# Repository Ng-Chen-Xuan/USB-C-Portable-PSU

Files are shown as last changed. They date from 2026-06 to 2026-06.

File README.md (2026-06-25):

# USB-C-Portable-PSU

> Speedrunning USB-C PD powered variable power supply

The USB-C-Portable-PSU Project is a portable variable power supply designed using KiCad v10.

The PCB was designed with a 4 layer stackup of SIG + PWR / GND / GND / PWR + SIG.

<table>
  <tr>
    <td align="center">
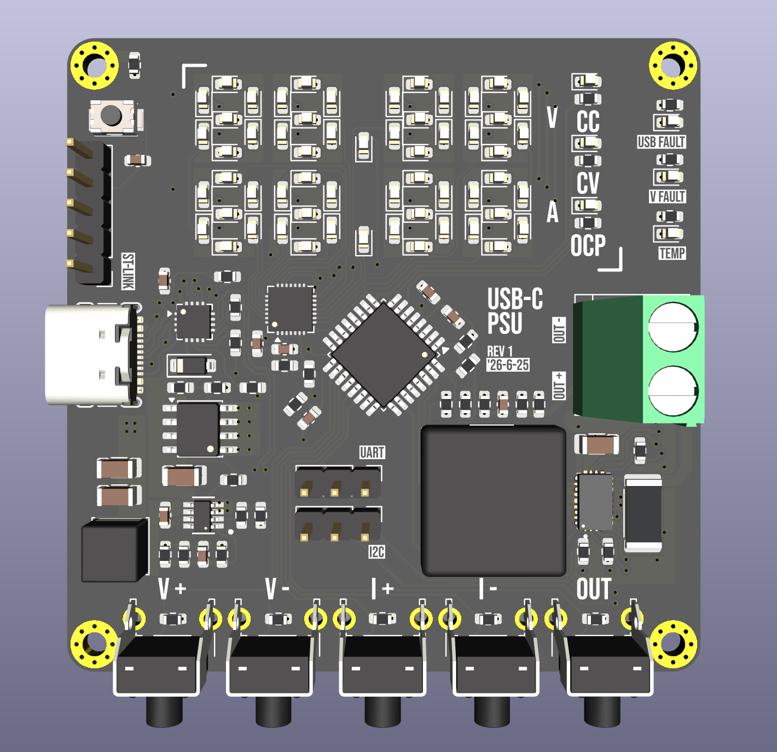
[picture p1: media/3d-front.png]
PCB Front
      <br>
      <b>PCB Front</b>
    </td>
    <td align="center">
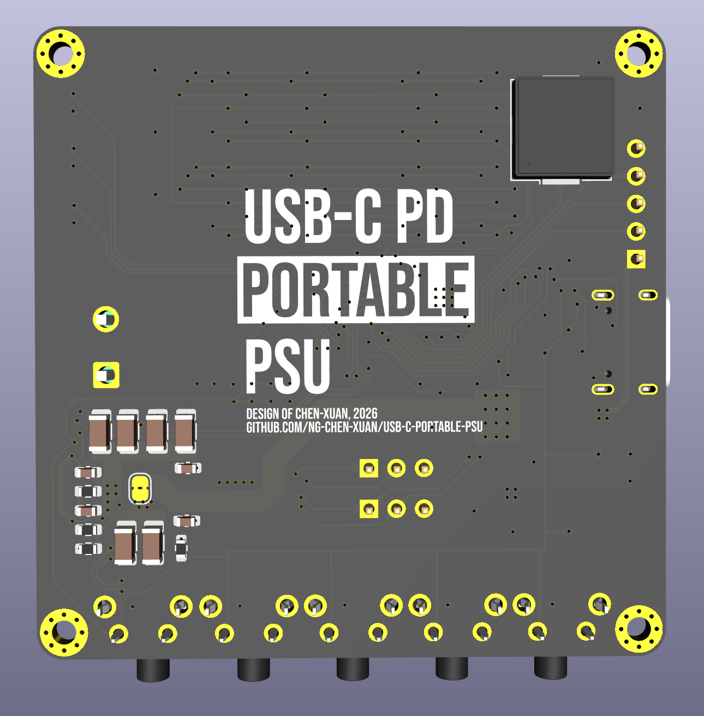
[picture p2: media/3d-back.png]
PCB Back
      <br>
      <b>PCB Back</b>
    </td>
  </tr>
</table>

## Objective

This PCB design serves as both an introduction to power electronics design, as well as a practical tool for hobbyist. Theoretical design practices learnt such as minimising trace inductance, buck-boost converter topology and USB-PD design can be tested in real-life conditions; Practice in programming an LED matrix display and experimentation of the STM32 ecosystem can be gained too.

## Features

* Input:

  * Supports USB-C PD up to 28 V / 3 A
* Output:

  * Variable Voltage Output Selection (3.3 V - 20 V)
  * Variable Constant Current Selection (up to 3 A)
  * Variable OCP Current Selection
* 7 Segment display for live voltage and current
* Safety:

  * Fault detection for USB-C PD
  * Fault detection for buck/boost converter
  * Temperature monitoring using thermistor
* ST-LINK programming header
* Exposed UART and I2C pins

<p align="center">
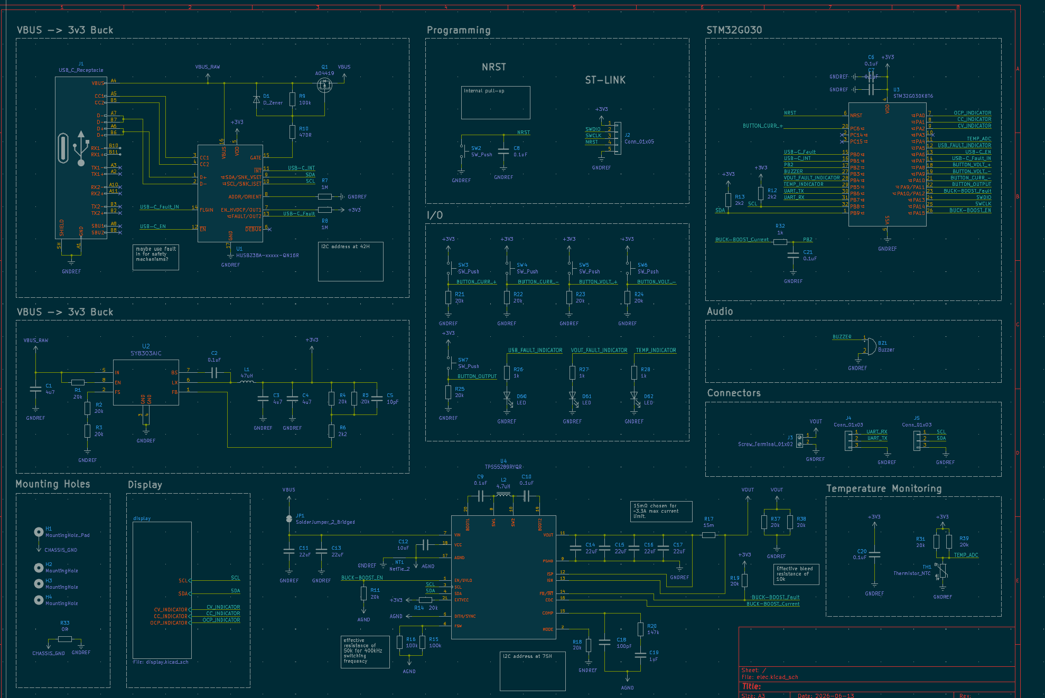
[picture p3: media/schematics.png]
Schematics
  <br>
  <b>Schematics</b>
</p>

<table>
  <tr>
    <td align="center">
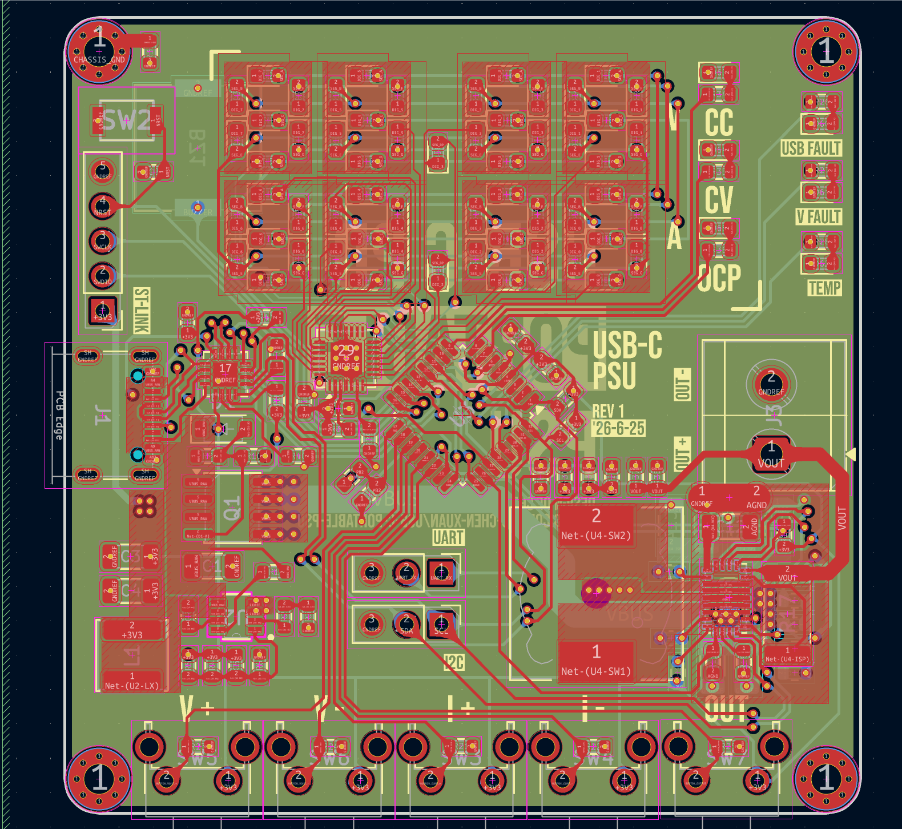
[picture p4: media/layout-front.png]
Layout Front
      <br>
      <b>Layout Front</b>
    </td>
    <td align="center">
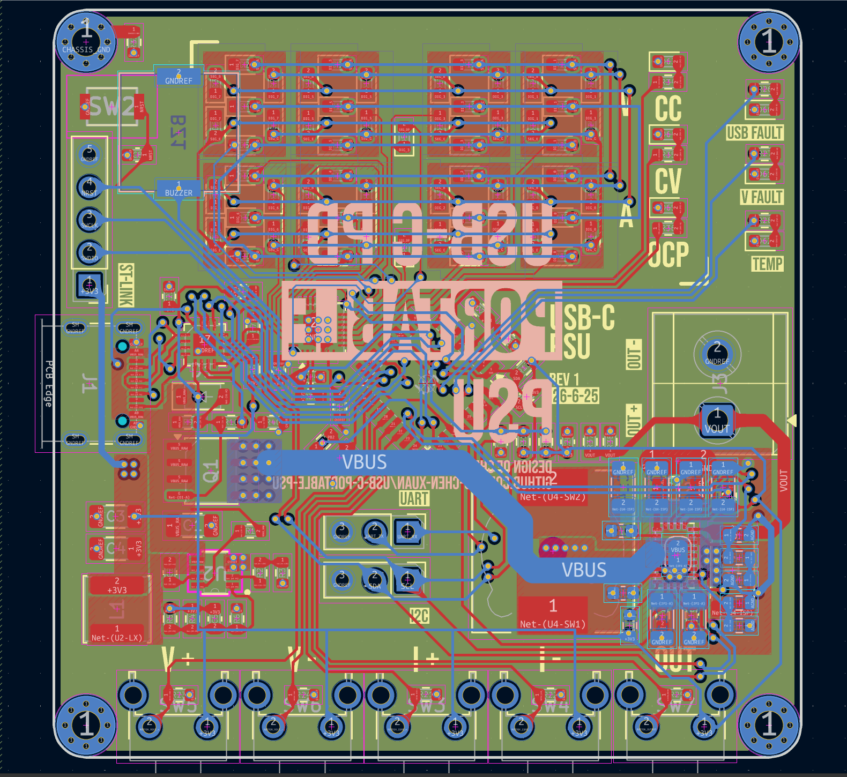
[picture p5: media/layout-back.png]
Layout Back
      <br>
      <b>Layout Back</b>
    </td>
  </tr>
</table>

## File Structure

* [elec/](elec/) - PCB Design Files (KiCad v10)

  * [pcb.pdf](elec/pcb.pdf) - PCB layout reference file
  * [schematics.pdf](elec/schematics.pdf) - PCB schematics reference file
  * [jlcpcb/production_files/](elec/jlcpcb/production_files) - Production files for JLCPCB. Includes BOM, CPL, Gerber files
* [media/](media/) - Images used in this README.md file
* [prod/](prod) - Miscellaneous production files
* [STM32G030K8T6/](STM32G030K8T6/) - STM32CubeMX Configuration file, STM32 Code
* [LICENSE](LICENSE), [LICENSES/](LICENSES/) - License files applicable to this project

## Manufacturing Notes

The design is intended to be manufactured using JLCPCB, with F.Cu assembled by JLCPCB and B.Cu hand-soldered to save on cost.

As of 2026-06-23, it is designed to be used without an enclosure.

## Bill of Materials

### Cost Summary

| Item | Supplier / Method | Cost | Notes |
| --- | --- | ---: | --- |
| JLCPCB order | JLCPCB | USD 144.44 | PCB, top-layer PCBA, extra PCB, and stencil |
| LCSC parts order | LCSC | USD 30.83 | Loose parts order |
| ST-LINK adapter | Taobao | CNY 52.32 | ST-LINK adapter |
| <strong>Total excluding Taobao</strong> | | <strong>USD 175.27</strong> | JLCPCB + LCSC only |
| <strong>Total excluding shipping</strong> | | <strong>USD 175.27 + CNY 52.32</strong> | Listed procurement cost excluding shipping  |

<strong>Total excluding shipping:</strong> USD 175.27 + CNY 52.32 <strong>Approximate USD equivalent:</strong> USD 182.99
Calculation: USD 144.44 + USD 30.83 + CNY 52.32 ≈ USD 182.99

---

### JLCPCB PCBA BOM

Top-layer PCBA only.
Minimum order quantity is <strong>5 PCBs</strong>, so PCBA quantities are shown both <strong>per PCB</strong> and <strong>for 5 PCBs</strong>.

SMD button <strong>SW2 / C115357</strong> is excluded from JLCPCB PCBA.

| Comment | Designator | Footprint | LCSC Part # | Qty / PCB | Total Qty for 5 PCBs |
| --- | --- | --- | --- | ---: | ---: |
| 0.1uF | C10, C2, C20, C21, C24, C6, C7, C8, C9 | C_0603_1608Metric | C14663 | 9 | 45 |
| 0R | R33 | R_0603_1608Metric | C21189 | 1 | 5 |
| 100k | R15, R16, R9 | R_0603_1608Metric | C25803 | 3 | 15 |
| 100pF | C18 | C_0603_1608Metric | C14858 | 1 | 5 |
| 10pF | C5 | C_0603_1608Metric | C1634 | 1 | 5 |
| 10uF | C12 | C_1206_3216Metric | C13585 | 1 | 5 |
| 147k | R20 | R_0603_1608Metric | C22878 | 1 | 5 |
| 15m | R17 | R_2512_6332Metric | C459682 | 1 | 5 |
| 1M | R40, R7, R8 | R_0603_1608Metric | C22935 | 3 | 15 |
| 1k | R26, R27, R28, R32, R34, R35, R36 | R_0603_1608Metric | C21190 | 7 | 35 |
| 1uF | C19, C22, C23 | C_0603_1608Metric | C15849 | 3 | 15 |
| 20k | R1, R11, R14, R18, R19, R2, R21, R22, R23, R24, R25, R29, R3, R30, R31, R37, R38, R39, R4, R41, R5 | R_0603_1608Metric | C4184 | 21 | 105 |
| 2k2 | R12, R13, R6 | R_0603_1608Metric | C4190 | 3 | 15 |
| 4.7uH | L2 | L_12x12mm_H8mm | C24548 | 1 | 5 |
| 470R | R10 | R_0603_1608Metric | C23179 | 1 | 5 |
| 47uH | L1 | L_APV_ANR5040 | C9392 | 1 | 5 |
| 4u7 | C1, C3, C4 | C_1206_3216Metric | C29823 | 3 | 15 |
| AO4419 | Q1 | SOIC-8-1EP_3.9x4.9mm_P1.27mm_EP2.29x3mm_ThermalVias | C29205 | 1 | 5 |
| Buzzer | BZ1 | Buzzer_Murata_PKMCS0909E | C391035 | 1 | 5 |
| D_Zener | D1 | D_SOD-123 | C2103 | 1 | 5 |
| HUSB238A-xxxxx-QN16R | U1 | WQFN-16-1EP_3x3mm_P0.5mm_EP1.75x1.75mm | C24833806 | 1 | 5 |
| IS31FL3731-QF | U6 | QFN-28-1EP_4x4mm_P0.4mm_EP2.3x2.3mm | C191206 | 1 | 5 |
| LED | D10, D11, D12, D13, D14, D15, D16, D17, D18, D19, D2, D20, D21, D22, D23, D24, D25, D26, D27, D28, D29, D3, D30, D31, D32, D33, D34, D35, D36, D37, D38, D39, D4, D40, D41, D42, D43, D44, D45, D46, D47, D48, D49, D5, D50, D51, D52, D53, D54, D55, D56, D57, D58, D59, D6, D60, D61, D62, D63, D64, D65, D7, D8, D9 | LED_0603_1608Metric | C2286 | 64 | 320 |
| STM32G030K8T6 | U3 | LQFP-32_7x7mm_P0.8mm | C431631 | 1 | 5 |
| SW_Push | SW3, SW4, SW5, SW6, SW7 | SW_Tactile_SPST_Angled_PTS645Vx58-2LFS | C86476 | 5 | 25 |
| SY8303AIC | U2 | TSOT_303AIC_SGY | C97054 | 1 | 5 |
| TPS55289RYQR | U4 | VREG_TPS55289RYQR | C5942077 | 1 | 5 |
| Thermistor_NTC | TH1 | R_0603_1608Metric | C13564 | 1 | 5 |
| USB_C_Receptacle | J1 | USB_C_Receptacle_GCT_USB4105-xx-A_16P_TopMnt_Horizontal | C5178539 | 1 | 5 |

<strong>JLCPCB PCBA placed quantity:</strong> 140 components per PCB <strong>Total placed components for MOQ 5:</strong> 700 components

---

### Excluded from JLCPCB PCBA

| Comment | Designator | Footprint  | LCSC Part # | Qty / PCB | Total Qty for 5 PCBs | Reason |
| --- | --- | --- | --- | ---: | ---: | --- |
| SW_Push | SW2 | SKRKAEE020 | C115357 | 1 | 5 | Excluded SMD button |

---

### Hand-Soldered / Not Included in JLCPCB PCBA

These parts are not included in JLCPCB PCBA and are intended to be hand-soldered.

| Comment | Designator | Footprint | Qty / PCB | Total Qty for 5 PCBs |
| --- | --- | --- | ---: | ---: |
| Screw_Terminal_01x02 | J3 | TerminalBlock_CUI_TB007-508-02_1x02_P5.08mm_Horizontal | 1 | 5 |
| Conn_01x05 | J2 | PinHeader_1x05_P2.54mm_Vertical | 1 | 5 |
| Conn_01x03 | J4 | PinHeader_1x03_P2.54mm_Vertical | 1 | 5 |
| Conn_01x03 | J5 | PinHeader_1x03_P2.54mm_Vertical | 1 | 5 |
| 22uF | C14 | C_1206_3216Metric | 1 | 5 |
| 22uF | C16 | C_1206_3216Metric | 1 | 5 |
| 22uF | C13 | C_1206_3216Metric | 1 | 5 |
| 22uF | C11 | C_1206_3216Metric | 1 | 5 |
| 22uF | C17 | C_1206_3216Metric | 1 | 5 |
| 22uF | C15 | C_1206_3216Metric | 1 | 5 |

---

### LCSC Separate Purchase / Spare Parts

These parts are purchased separately from LCSC as loose parts, including spare parts, rework parts, hand-soldered parts, and parts excluded from JLCPCB PCBA.

| LCSC Part # | MPN | Manufacturer | Package | Description | Qty | Unit Price (USD) | Extended Price (USD) |
| --- | --- | --- | --- | --- | --: | ---: | ---: |
| C342620 | C3216X5R1V226MTJ00E | TDK | 1206 | 22uF ±20% 35V Ceramic Capacitor X5R 1206 |  30 | 0.3812 | 11.44 |
| C22878 | 0603WAF1473T5E | UNI-ROYAL | 0603 | 147kΩ ±1% 100mW 0603 Thick Film Resistor | 100 | 0.0022 | 0.22 |
| C14858 | CL10C101JB8NNNC | Samsung Electro-Mechanics | 0603 | 100pF ±5% 50V Ceramic Capacitor C0G 0603 | 100 | 0.0085 | 0.85 |
| C5199872 | CL10B105KB8NQNC | Samsung Electro-Mechanics | 0603 | 1uF ±10% 50V Ceramic Capacitor X7R 0603 | 100 | 0.0262 | 2.62 |
| C2906980 | FRC0603F1003TS | FOJAN | 0603 | 100kΩ ±1% 100mW 0603 Thick Film Resistor | 100 | 0.0019 | 0.19 |
| C2907011 | FRC0603F2002TS | FOJAN | 0603 | 20kΩ ±1% 100mW 0603 Thick Film Resistor | 100 | 0.0018 | 0.18 |
| C1591 | CL10B104KB8NNNC | Samsung Electro-Mechanics | 0603 | 100nF ±10% 50V Ceramic Capacitor X7R 0603 | 100 | 0.0142 | 1.42 |
| C391035 | FUET-9018 | FUET | SMD,9x9mm | Buzzers Passive (Externally Driven) Piezoelectric 4kHz 65dB SMD,9x9mm |  10 | 0.4248 | 4.25 |
| C115357 | SKRKAEE020 | ALPSALPINE | SMD,3.9x2.9mm | Tactile Switch SPST 2mm 3.9mm x 2.9mm Surface Mount |  20 | 0.1333 | 2.67 |
| C3816270 | TB007-508-02BE | CUI | Through Hole,P=5.08mm | 2 Position Wire to Board Terminal Block 5.08mm |  10 | 0.6764 | 6.76 |
| C2907075 | FRC0603F9103TS | FOJAN | 0603 | 910kΩ ±1% 100mW 0603 Thick Film Resistor | 100 | 0.0023 | 0.23 |

<strong>LCSC order total:</strong> USD 30.83

---

### Taobao Separate Purchase

| Item | Supplier | Qty | Cost | Notes |
| --- | --- | --: | ---: | --- |
| ST-LINK adapter | Taobao | 1 | CNY 52.32 | Used for programming/debugging adapter setup |

---

### Notes

* JLCPCB PCBA is for top-layer assembly only.
* JLCPCB's PCBA minimum order quantity is 5 PCBs, so PCBA quantities are shown both per PCB and for 5 PCBs.
* The SMD button `SW2 / C115357` is excluded from JLCPCB PCBA and purchased separately from LCSC.
* Hand-soldered parts are not included in JLCPCB PCBA.
* Loose LCSC parts include spare parts, rework parts, hand-soldered parts, and parts excluded from JLCPCB PCBA.
* The ST-LINK adapter is purchased separately from Taobao.

<table>
  <tr>
    <td align="center">
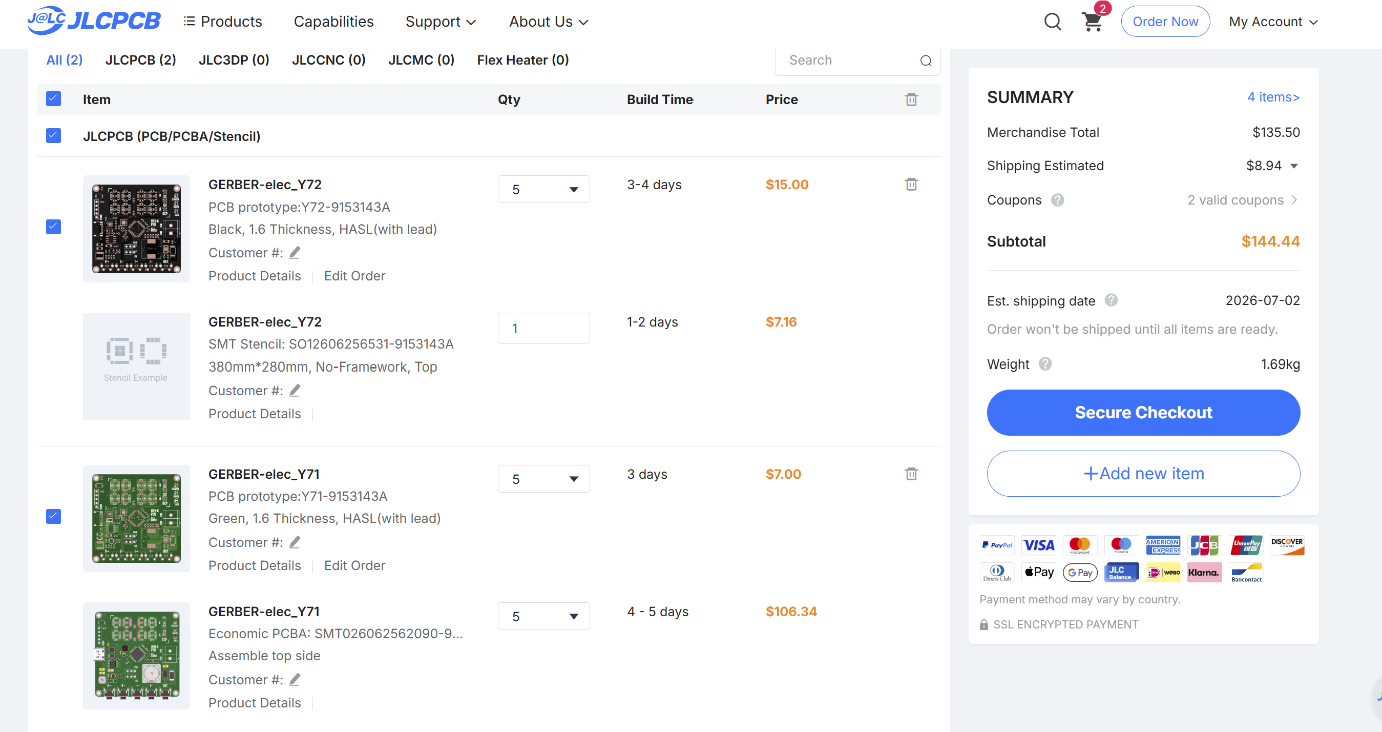
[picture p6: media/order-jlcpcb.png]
JLCPCB Order
      <br>
      <b>JLCPCB Order</b>
    </td>
    <td align="center">
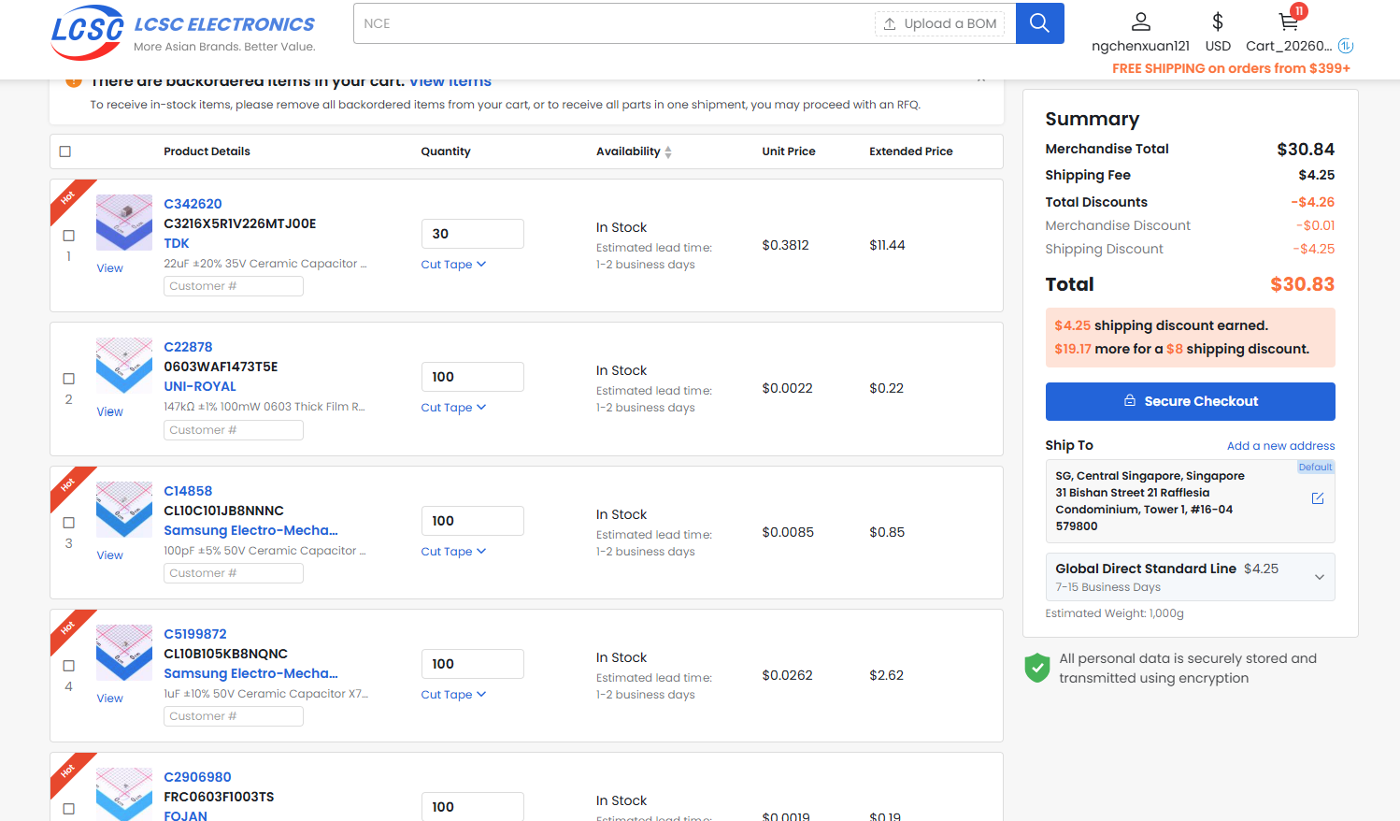
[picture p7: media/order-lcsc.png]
LCSC Order
      <br>
      <b>LCSC Order</b>
    </td>
  </tr>
</table>

## License

This project uses multiple licenses:

* Hardware design files, including schematics, PCB layout files, Gerbers, BOM files, pick-and-place files, mechanical CAD files, and enclosure designs: <strong>CERN-OHL-S-2.0</strong>
* Firmware and software source code: <strong>GPL-3.0-only</strong>
* Documentation, images, diagrams, and build instructions: <strong>CC-BY-SA-4.0</strong>

Full license texts are available in the `LICENSES/` directory.

## Contact

Contact the author at [contact@ngchenxuan.com](mailto:contact@ngchenxuan.com) for any enquiries related to this project.

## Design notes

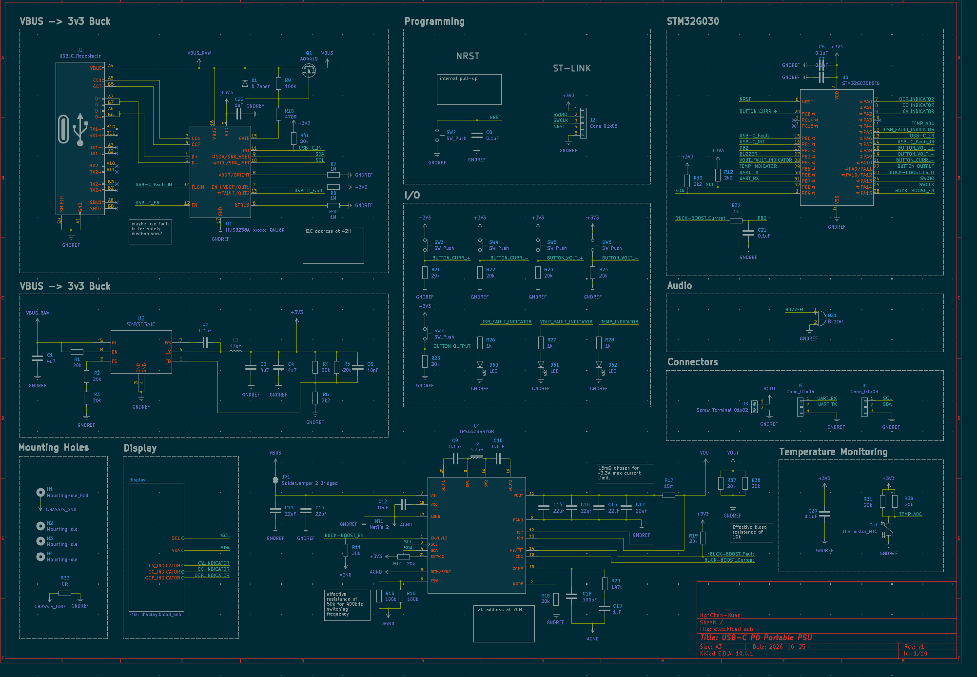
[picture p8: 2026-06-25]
media/schematic.png

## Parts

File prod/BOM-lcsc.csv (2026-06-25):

Index | LCSC# | MPN | Manufacturer | Package | Customer # | Description | RoHS | Quantity | MOQ | Multiple | Unit Price($) | Extended Price($) | Product Link
1 | C342620 | C3216X5R1V226MTJ00E | TDK | 1206 |  | 22uF ±20% 35V Ceramic Capacitor X5R 1206 | yes | 30 | 10 | 10 | 0.3812 | 11.44 | https://www.lcsc.com/product-detail/C342620.html
2 | C22878 | 0603WAF1473T5E | UNI-ROYAL | 0603 |  | 147kΩ ±1% 100mW 0603 Thick Film Resistor | yes | 100 | 100 | 100 | 0.0022 | 0.22 | https://www.lcsc.com/product-detail/C22878.html
3 | C14858 | CL10C101JB8NNNC | Samsung Electro-Mechanics | 0603 |  | 100pF ±5% 50V Ceramic Capacitor C0G 0603 | yes | 100 | 100 | 100 | 0.0085 | 0.85 | https://www.lcsc.com/product-detail/C14858.html
4 | C5199872 | CL10B105KB8NQNC | Samsung Electro-Mechanics | 0603 |  | 1uF ±10% 50V Ceramic Capacitor X7R 0603 | yes | 100 | 50 | 50 | 0.0262 | 2.62 | https://www.lcsc.com/product-detail/C5199872.html
5 | C2906980 | FRC0603F1003TS | FOJAN | 0603 |  | 100kΩ ±1% 100mW 0603 Thick Film Resistor | yes | 100 | 100 | 100 | 0.0019 | 0.19 | https://www.lcsc.com/product-detail/C2906980.html
6 | C2907011 | FRC0603F2002TS | FOJAN | 0603 |  | 20kΩ ±1% 100mW 0603 Thick Film Resistor | yes | 100 | 100 | 100 | 0.0018 | 0.18 | https://www.lcsc.com/product-detail/C2907011.html
7 | C1591 | CL10B104KB8NNNC | Samsung Electro-Mechanics | 0603 |  | 100nF ±10% 50V Ceramic Capacitor X7R 0603 | yes | 100 | 100 | 100 | 0.0142 | 1.42 | https://www.lcsc.com/product-detail/C1591.html
8 | C391035 | FUET-9018 | FUET | SMD,9x9mm |  | Buzzers Passive (Externally Driven) Piezoelectric 4kHz 65dB SMD,9x9mm | yes | 10 | 1 | 1 | 0.4248 | 4.25 | https://www.lcsc.com/product-detail/C391035.html
9 | C115357 | SKRKAEE020 | ALPSALPINE | SMD,3.9x2.9mm |  | Tactile Switch SPST 2mm 3.9mm x 2.9mm Surface Mount | yes | 20 | 5 | 5 | 0.1333 | 2.67 | https://www.lcsc.com/product-detail/C115357.html
10 | C3816270 | TB007-508-02BE | CUI | Through Hole,P=5.08mm |  | 2 Position Wire to Board Terminal Block 5.08mm | yes | 10 | 1 | 1 | 0.6764 | 6.76 | https://www.lcsc.com/product-detail/C3816270.html
11 | C2907075 | FRC0603F9103TS | FOJAN | 0603 |  | 910kΩ ±1% 100mW 0603 Thick Film Resistor | yes | 100 | 100 | 100 | 0.0023 | 0.23 | https://www.lcsc.com/product-detail/C2907075.html

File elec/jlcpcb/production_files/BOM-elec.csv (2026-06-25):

Comment | Designator | Footprint | LCSC | Quantity
0.1uF | C10,C2,C20,C21,C24,C6,C7,C8,C9 | C_0603_1608Metric | C14663 | 9
0R | R33 | R_0603_1608Metric | C21189 | 1
100k | R15,R16,R9 | R_0603_1608Metric | C25803 | 3
100pF | C18 | C_0603_1608Metric | C14858 | 1
10pF | C5 | C_0603_1608Metric | C1634 | 1
10uF | C12 | C_1206_3216Metric | C13585 | 1
147k | R20 | R_0603_1608Metric | C22878 | 1
15m | R17 | R_2512_6332Metric | C459682 | 1
1M | R40,R7,R8 | R_0603_1608Metric | C22935 | 3
1k | R26,R27,R28,R32,R34,R35,R36 | R_0603_1608Metric | C21190 | 7
1uF | C19,C22,C23 | C_0603_1608Metric | C15849 | 3
20k | R1,R11,R14,R18,R19,R2,R21,R22,R23,R24,R25,R29,R3,R30,R31,R37,R38,R39,R4,R41,R5 | R_0603_1608Metric | C4184 | 21
2k2 | R12,R13,R6 | R_0603_1608Metric | C4190 | 3
4.7uH | L2 | L_12x12mm_H8mm | C24548 | 1
470R | R10 | R_0603_1608Metric | C23179 | 1
47uH | L1 | L_APV_ANR5040 | C9392 | 1
4u7 | C1,C3,C4 | C_1206_3216Metric | C29823 | 3
AO4419 | Q1 | SOIC-8-1EP_3.9x4.9mm_P1.27mm_EP2.29x3mm_ThermalVias | C29205 | 1
Buzzer | BZ1 | Buzzer_Murata_PKMCS0909E | C391035 | 1
D_Zener | D1 | D_SOD-123 | C2103 | 1
HUSB238A-xxxxx-QN16R | U1 | WQFN-16-1EP_3x3mm_P0.5mm_EP1.75x1.75mm | C24833806 | 1
IS31FL3731-QF | U6 | QFN-28-1EP_4x4mm_P0.4mm_EP2.3x2.3mm | C191206 | 1
LED | D10,D11,D12,D13,D14,D15,D16,D17,D18,D19,D2,D20,D21,D22,D23,D24,D25,D26,D27,D28,D29,D3,D30,D31,D32,D33,D34,D35,D36,D37,D38,D39,D4,D40,D41,D42,D43,D44,D45,D46,D47,D48,D49,D5,D50,D51,D52,D53,D54,D55,D56,D57,D58,D59,D6,D60,D61,D62,D63,D64,D65,D7,D8,D9 | LED_0603_1608Metric | C2286 | 64
STM32G030K8T6 | U3 | LQFP-32_7x7mm_P0.8mm | C431631 | 1
SW_Push | SW2 | SKRKAEE020 | C115357 | 1
SW_Push | SW3,SW4,SW5,SW6,SW7 | SW_Tactile_SPST_Angled_PTS645Vx58-2LFS | C86476 | 5
SY8303AIC | U2 | TSOT_303AIC_SGY | C97054 | 1
TPS55289RYQR | U4 | VREG_TPS55289RYQR | C5942077 | 1
Thermistor_NTC | TH1 | R_0603_1608Metric | C13564 | 1
USB_C_Receptacle | J1 | USB_C_Receptacle_GCT_USB4105-xx-A_16P_TopMnt_Horizontal | C5178539 | 1
Screw_Terminal_01x02 | J3 | TerminalBlock_CUI_TB007-508-02_1x02_P5.08mm_Horizontal |  | 1
Conn_01x05 | J2 | PinHeader_1x05_P2.54mm_Vertical |  | 1
Conn_01x03 | J4 | PinHeader_1x03_P2.54mm_Vertical |  | 1
Conn_01x03 | J5 | PinHeader_1x03_P2.54mm_Vertical |  | 1
22uF | C14 | C_1206_3216Metric |  | 1
22uF | C16 | C_1206_3216Metric |  | 1
22uF | C13 | C_1206_3216Metric |  | 1
22uF | C11 | C_1206_3216Metric |  | 1
22uF | C17 | C_1206_3216Metric |  | 1
22uF | C15 | C_1206_3216Metric |  | 1

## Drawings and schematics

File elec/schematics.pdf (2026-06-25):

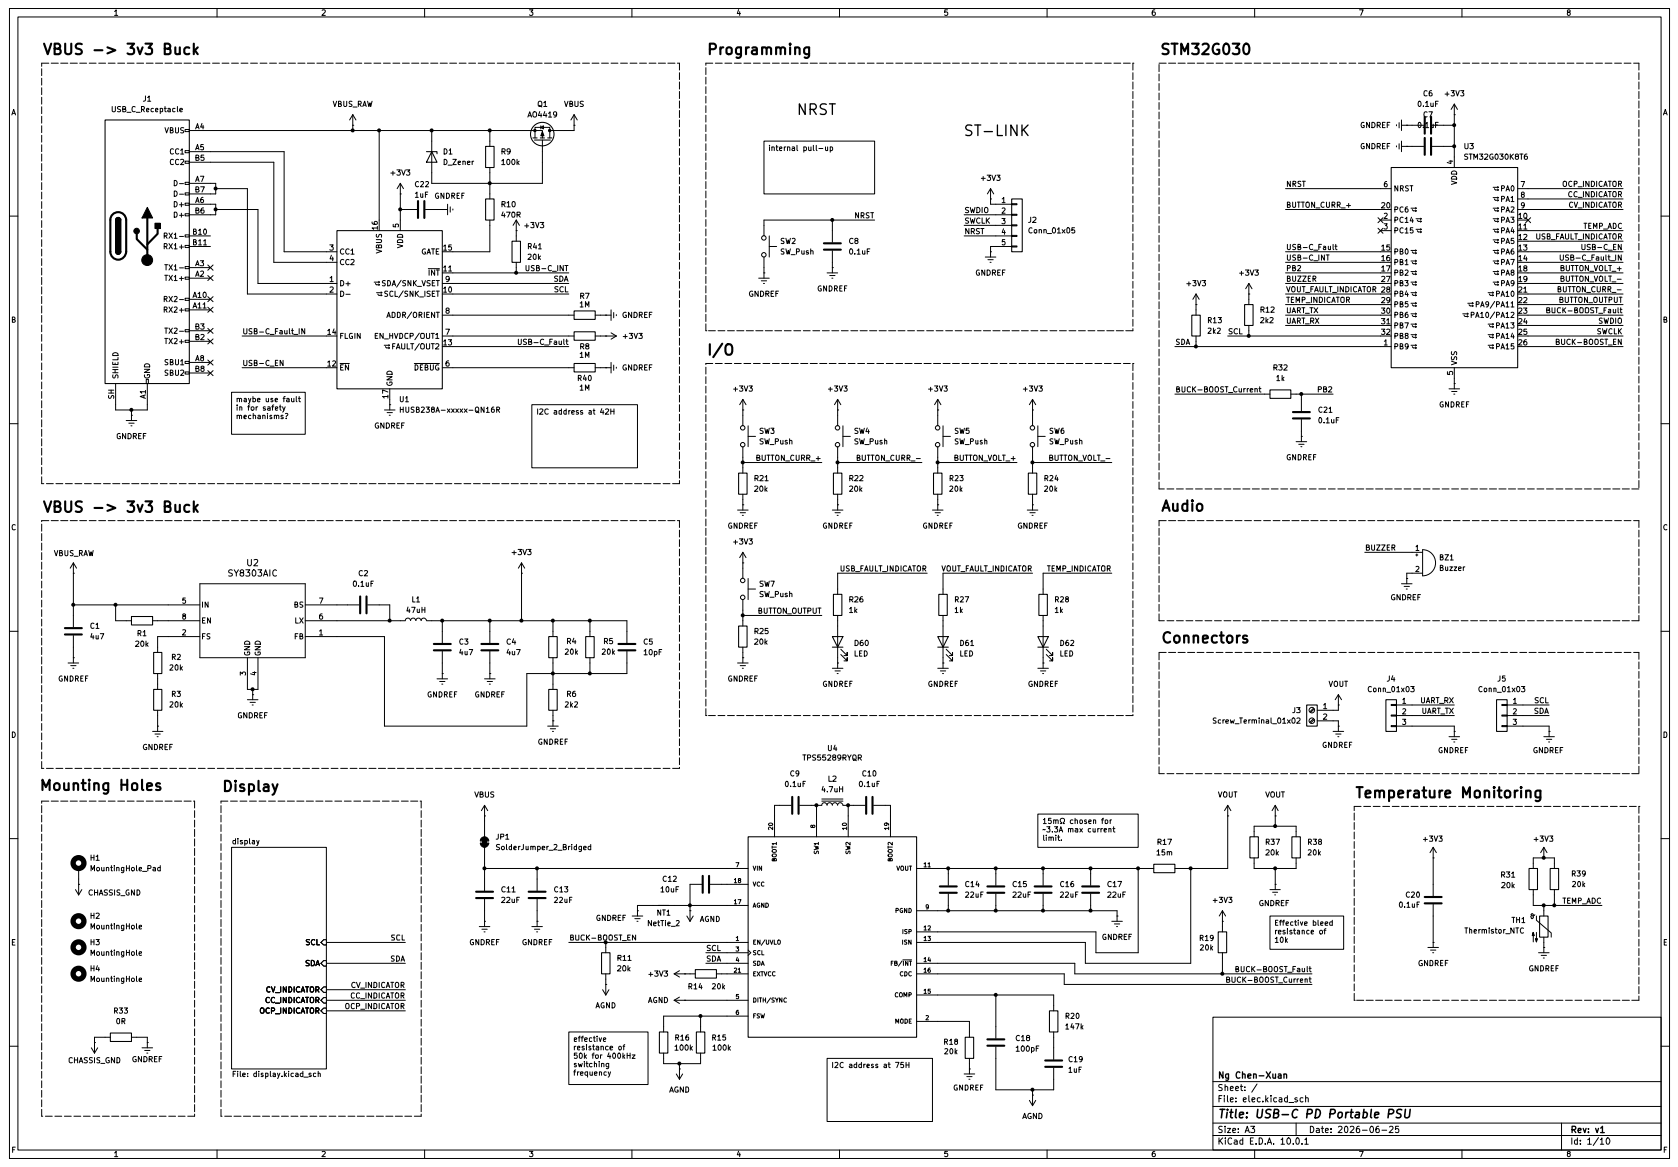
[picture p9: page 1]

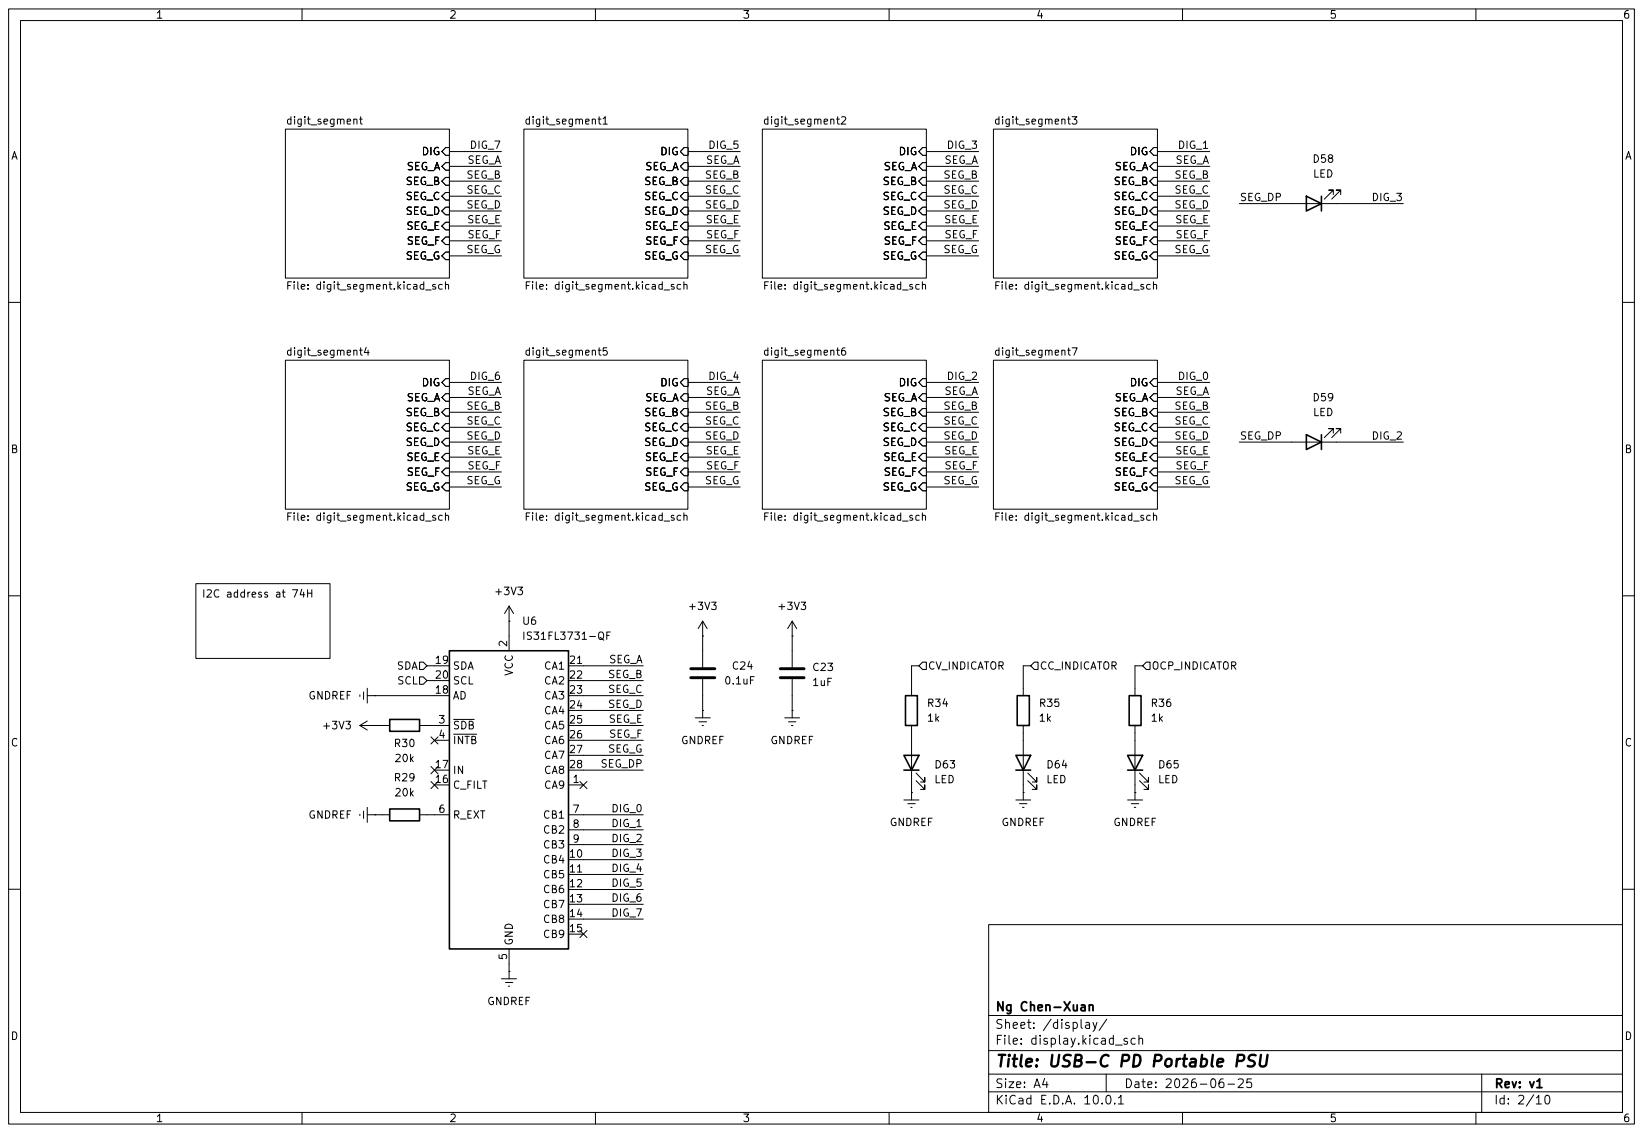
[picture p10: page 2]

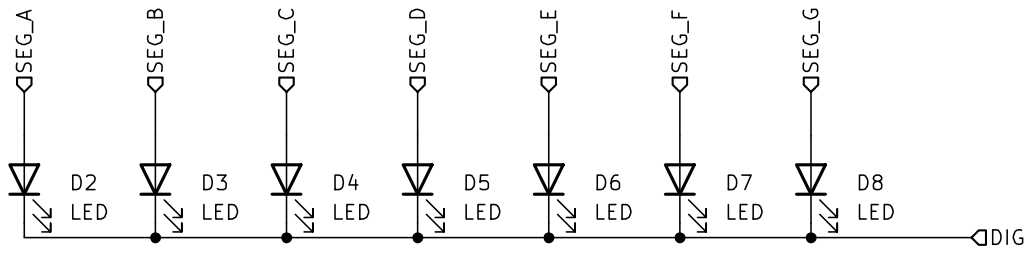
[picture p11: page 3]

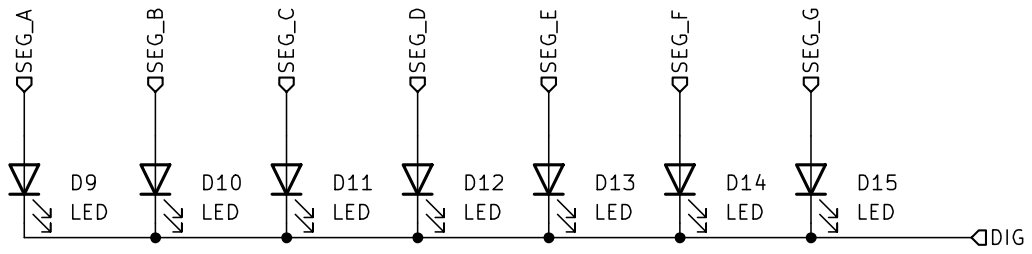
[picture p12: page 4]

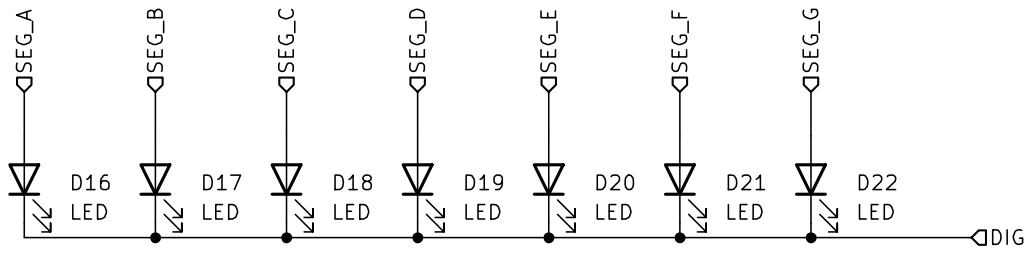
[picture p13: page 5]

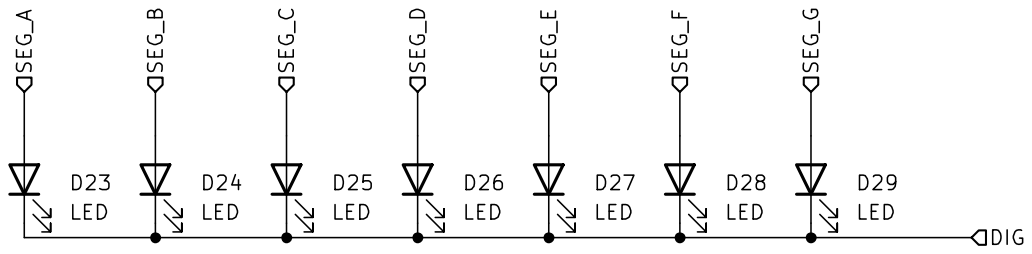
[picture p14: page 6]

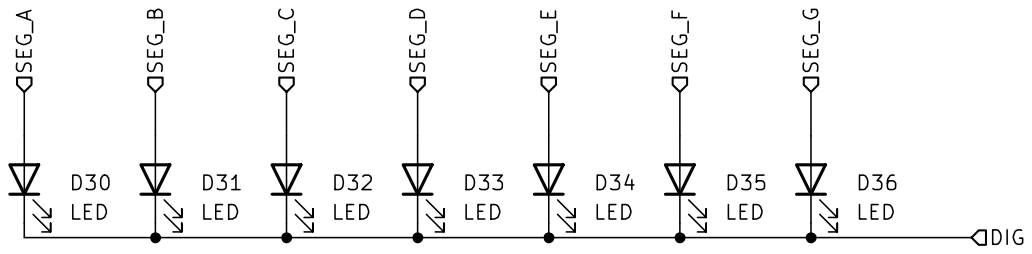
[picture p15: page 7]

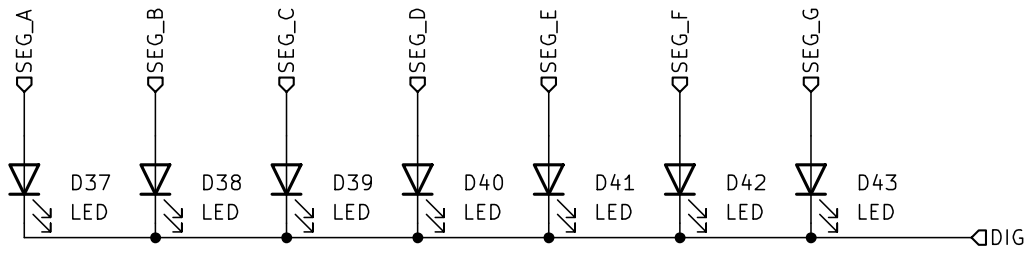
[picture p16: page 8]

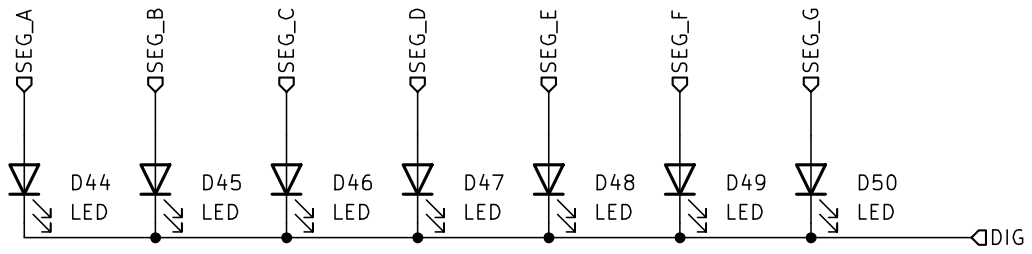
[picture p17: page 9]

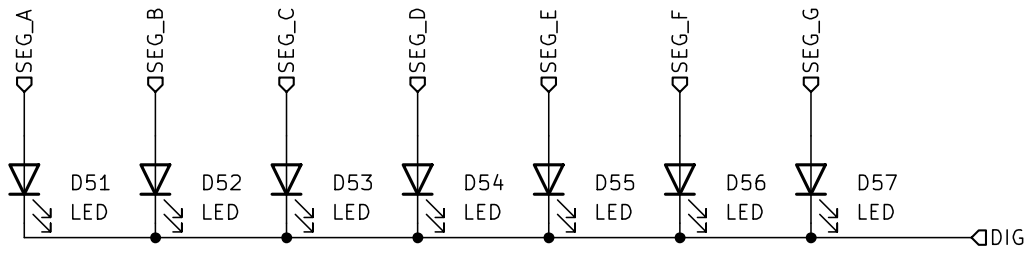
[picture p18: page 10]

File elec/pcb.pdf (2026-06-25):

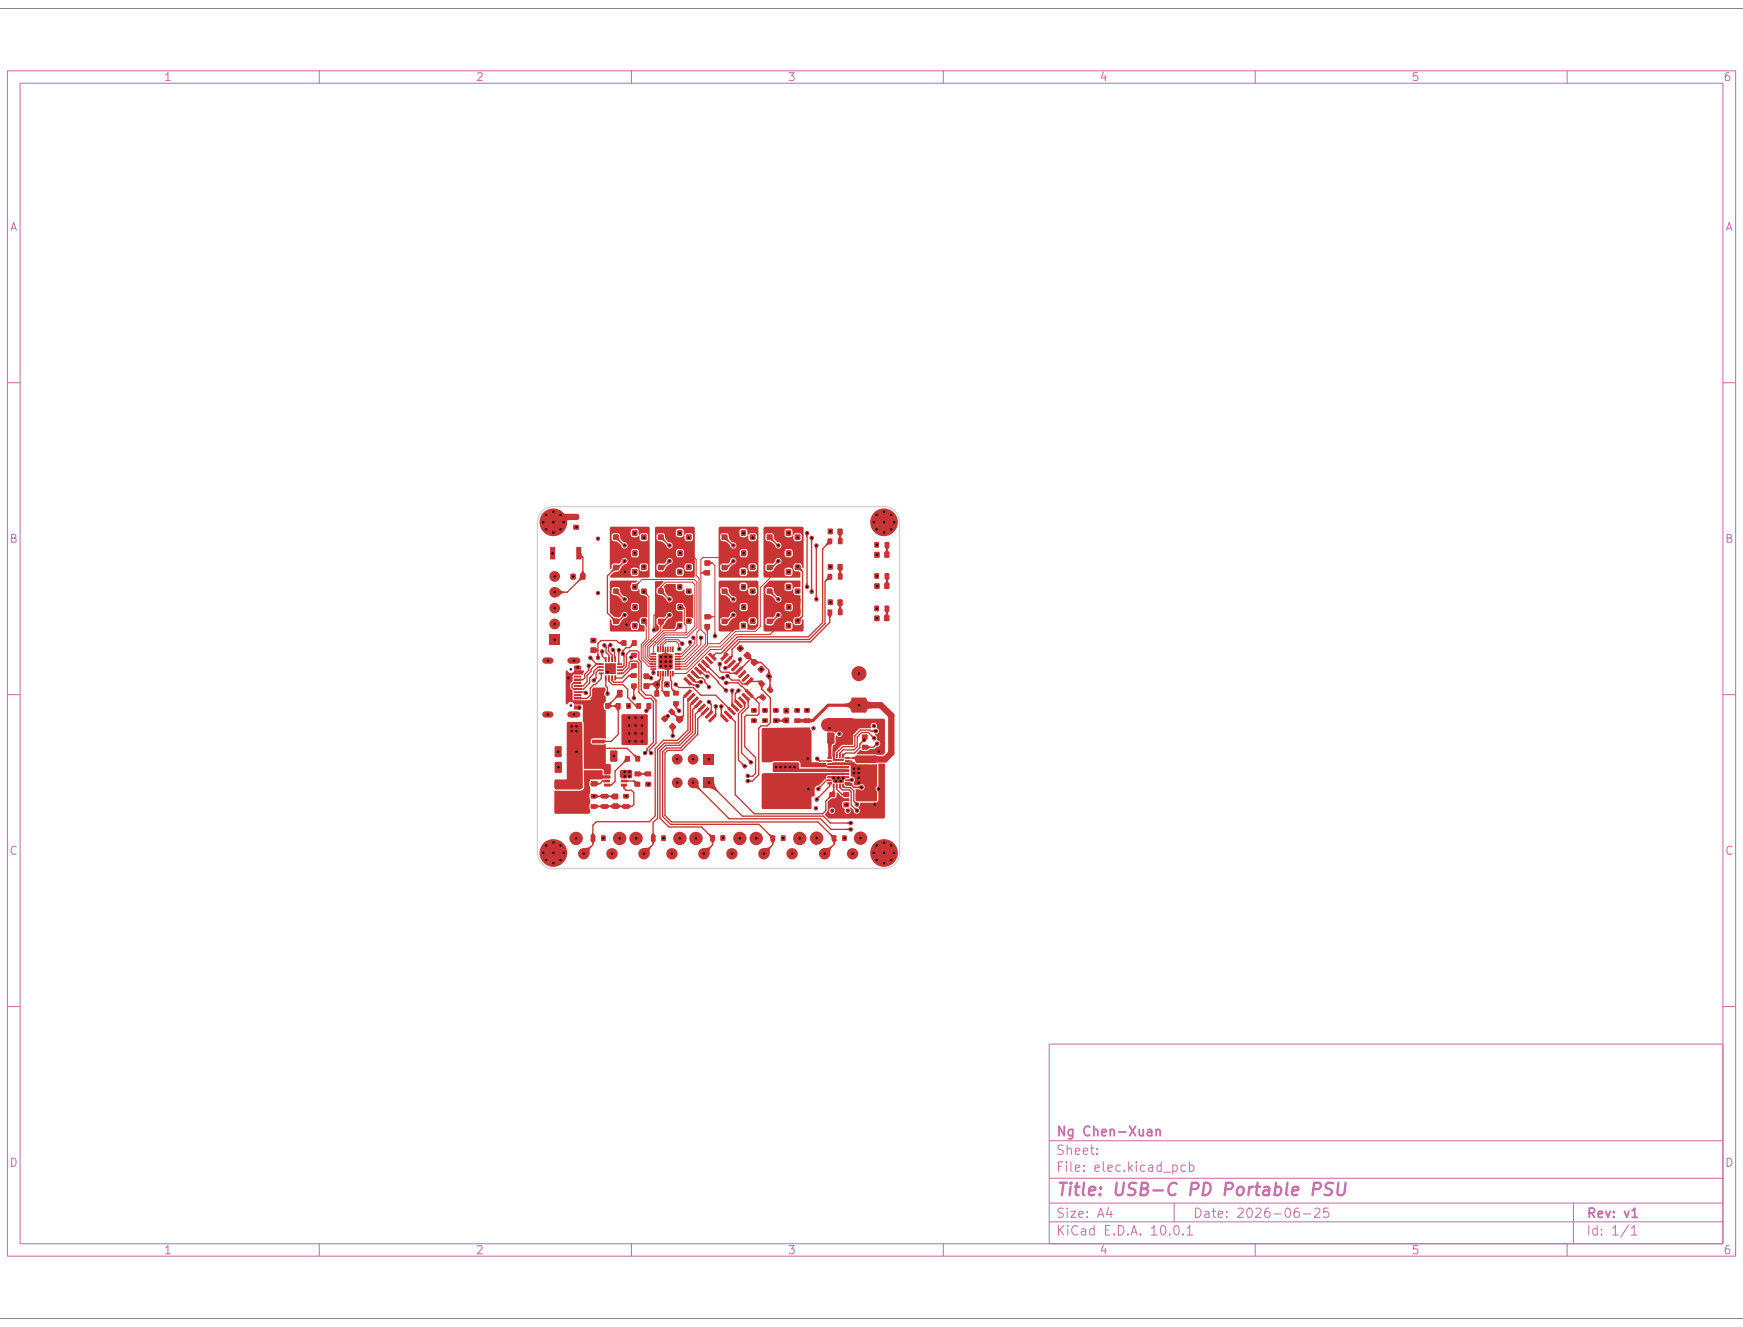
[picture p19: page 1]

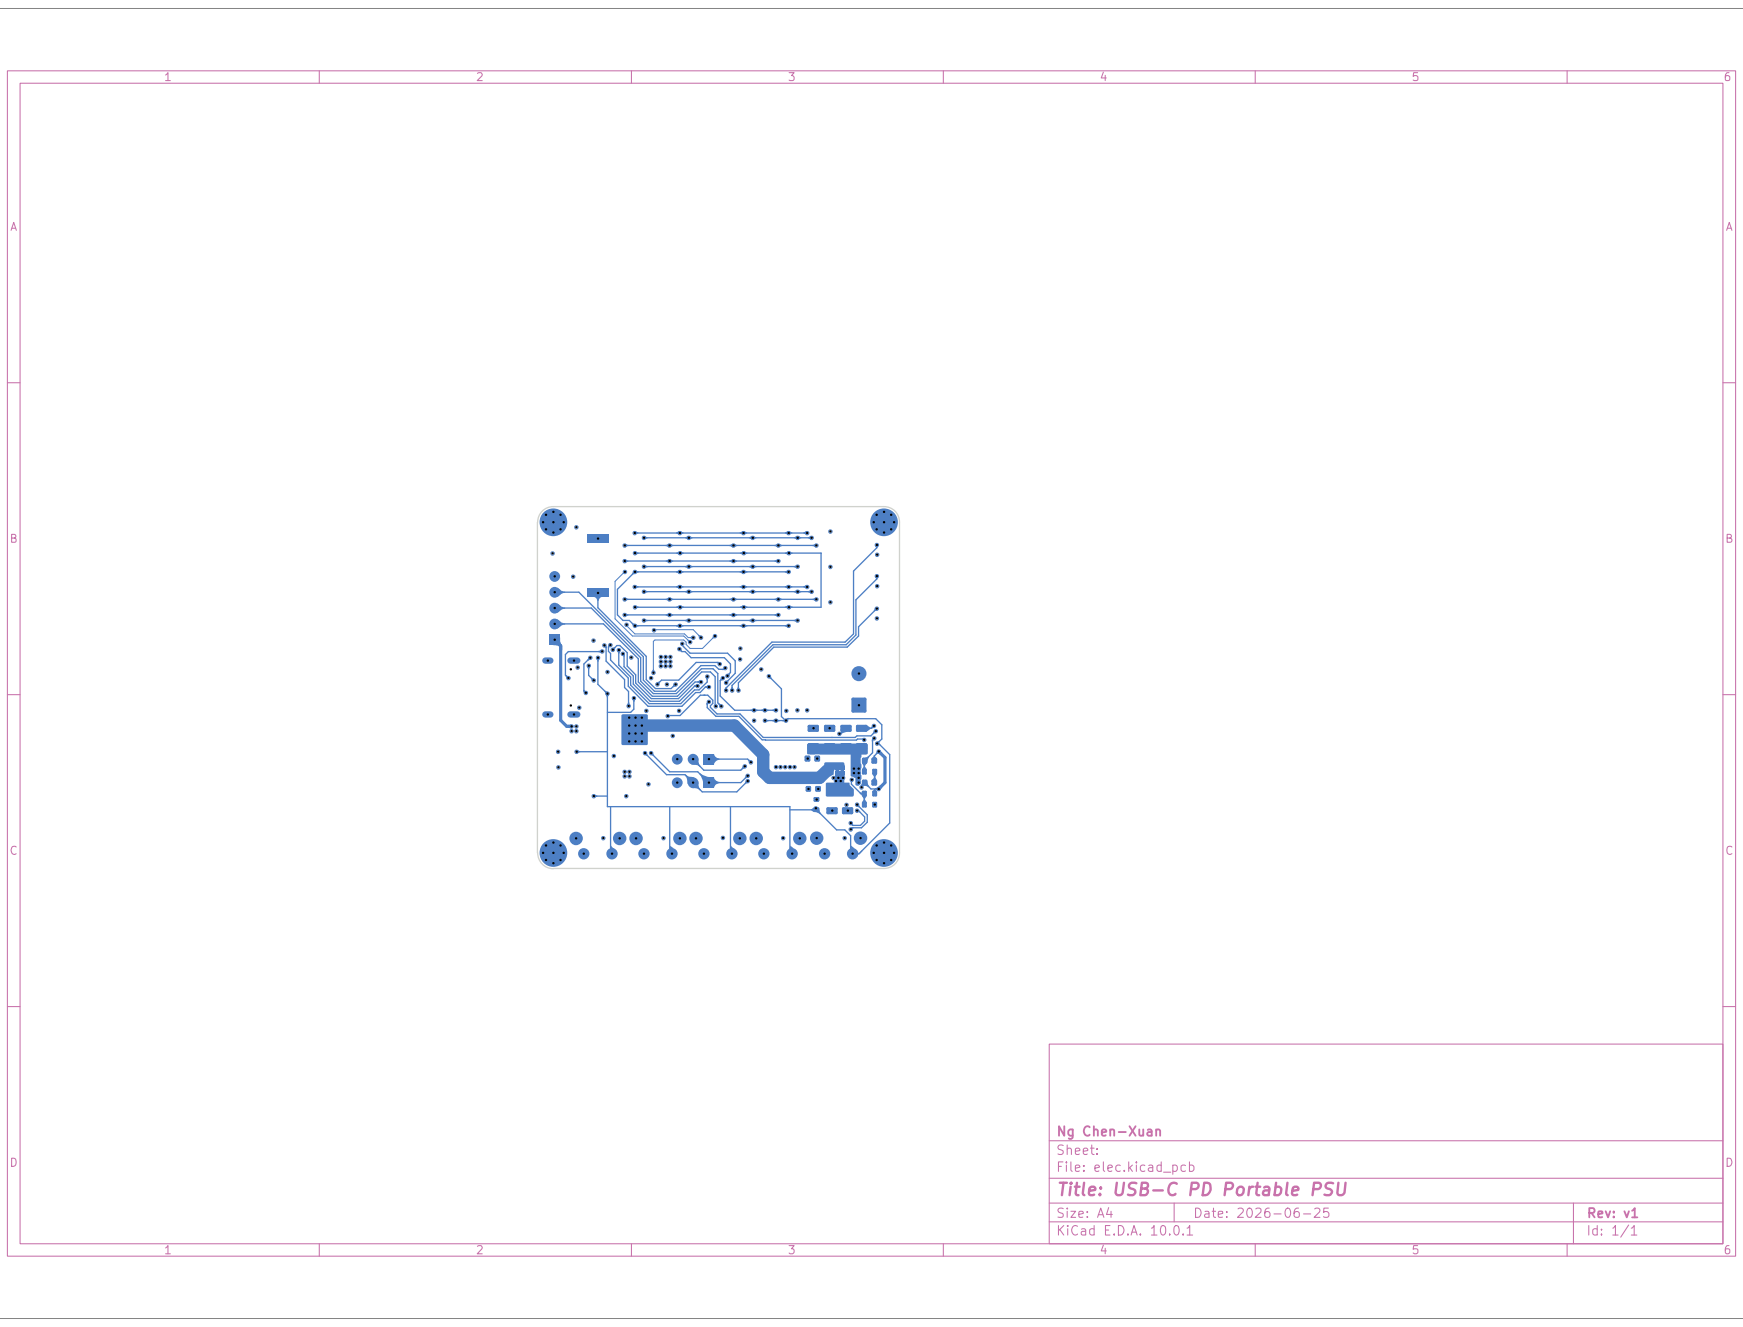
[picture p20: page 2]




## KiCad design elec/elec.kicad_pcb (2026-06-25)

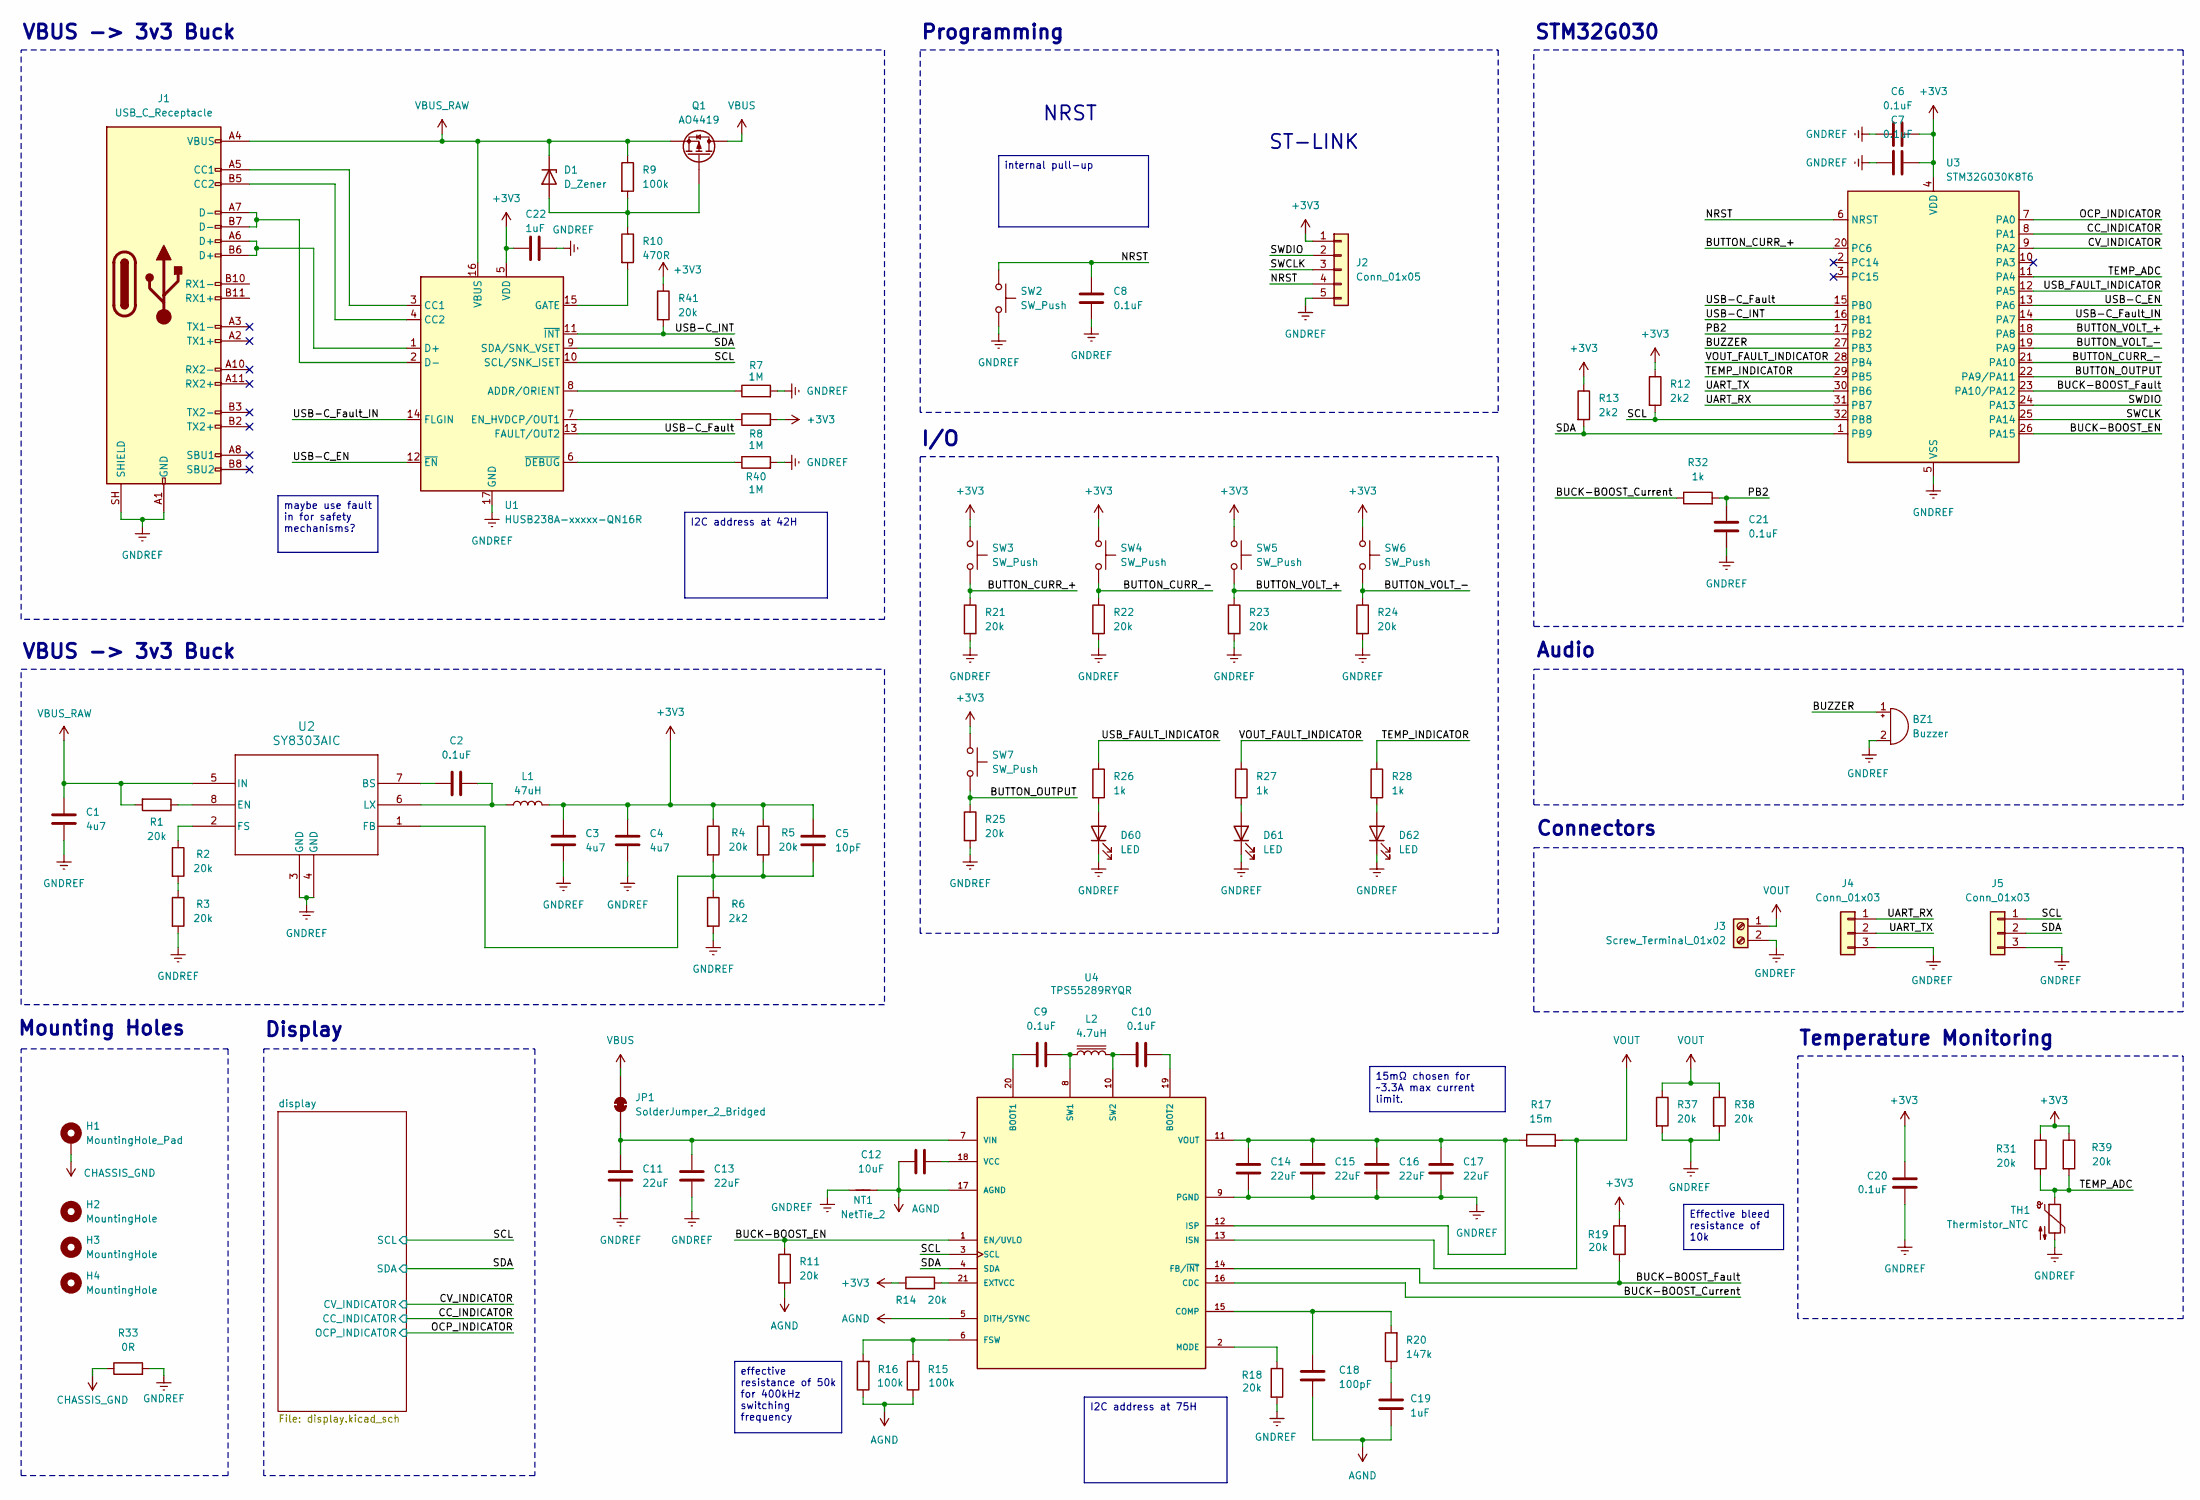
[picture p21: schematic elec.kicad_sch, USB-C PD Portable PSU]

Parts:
BZ1: Buzzer; Buzzer_Murata_PKMCS0909E; LCSC C391035
C1, C3, C4: 4u7; C_1206_3216Metric; LCSC C29823
C2, C6, C7, C8, C9, C10, C20, C21: 0.1uF; C_0603_1608Metric; LCSC C14663
C5: 10pF; C_0603_1608Metric; LCSC C1634
C11, C13, C14, C15, C16, C17: 22uF; C_1206_3216Metric
C12: 10uF; C_1206_3216Metric; LCSC C13585
C18: 100pF; C_0603_1608Metric; LCSC C14858
C19, C22: 1uF; C_0603_1608Metric; LCSC C15849
D1: D_Zener; D_SOD-123; LCSC C2103
D60, D61, D62: LED; LED_0603_1608Metric; LCSC C2286
H1: MountingHole_Pad; MountingHole_2.2mm_M2_Pad_Via
H2, H3, H4: MountingHole; MountingHole_2.2mm_M2_Pad_Via
J1: USB_C_Receptacle; USB_C_Receptacle_GCT_USB4105-xx-A_16P_TopMnt_Horizontal; LCSC C5178539
J2: Conn_01x05; PinHeader_1x05_P2.54mm_Vertical
J3: Screw_Terminal_01x02; TerminalBlock_CUI_TB007-508-02_1x02_P5.08mm_Horizontal
J4, J5: Conn_01x03; PinHeader_1x03_P2.54mm_Vertical
JP1: SolderJumper_2_Bridged; SolderJumper-2_P1.3mm_Bridged2Bar_RoundedPad1.0x1.5mm
L1: 47uH; L_APV_ANR5040; LCSC C9392
L2: 4.7uH; L_12x12mm_H8mm; LCSC C24548
NT1: NetTie_2; NetTie-2_SMD_Pad2.0mm
Q1: AO4419; SOIC-8-1EP_3.9x4.9mm_P1.27mm_EP2.29x3mm_ThermalVias; LCSC C29205
R1, R2, R3, R4, R5, R11, R14, R18, R19, R21, R22, R23, R24, R25, R31, R37, R38, R39: 20k; R_0603_1608Metric; LCSC C4184
R6, R12, R13: 2k2; R_0603_1608Metric; LCSC C4190
R7, R8, R40: 1M; R_0603_1608Metric; LCSC C22935
R9, R15, R16: 100k; R_0603_1608Metric; LCSC C25803
R10: 470R; R_0603_1608Metric; LCSC C23179
R17: 15m; R_2512_6332Metric; LCSC C459682
R20: 147k; R_0603_1608Metric; LCSC C22878
R26, R27, R28, R32: 1k; R_0603_1608Metric; LCSC C21190
R33: 0R; R_0603_1608Metric; LCSC C21189
R41: 20k; R_0603_1608Metric; LCSC C23179
SW2: SW_Push; SKRKAEE020; LCSC C115357
SW3, SW4, SW5, SW6, SW7: SW_Push; SW_Tactile_SPST_Angled_PTS645Vx58-2LFS; LCSC C86476
TH1: Thermistor_NTC; R_0603_1608Metric; LCSC C13564
U1: HUSB238A-xxxxx-QN16R; WQFN-16-1EP_3x3mm_P0.5mm_EP1.75x1.75mm; LCSC C24833806
U2: SY8303AIC; TSOT_303AIC_SGY; LCSC C97054
U3: STM32G030K8T6; LQFP-32_7x7mm_P0.8mm; LCSC C431631
U4: TPS55289RYQR; VREG_TPS55289RYQR; PARTREV August 2022; LCSC C5942077

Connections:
+3V3: C3.1, C4.1, C5.1, C6.2, C7.2, C20.2, C22.1, J2.1, L1.2, R4.1, R5.1, R8.2, R12.1, R13.1, R14.1, R19.2, R31.1, R39.1, R41.1, SW3.1, SW4.1, SW5.1, SW6.1, SW7.1, U1.5 (VDD), U3.4 (VDD); also elsewhere on the board
/BUCK-BOOST_Current: R32.1, U4.16 (CDC)
/BUCK-BOOST_EN: R11.1, U3.26 (PA15), U4.1 (EN/UVLO)
/BUCK-BOOST_Fault: R19.1, U3.23 (PA10/PA12), U4.14 (FB/~INT)
/BUTTON_CURR_+: R21.1, SW3.2, U3.20 (PC6)
/BUTTON_CURR_-: R22.1, SW4.2, U3.21 (PA10)
/BUTTON_OUTPUT: R25.1, SW7.2, U3.22 (PA9/PA11)
/BUTTON_VOLT_+: R23.1, SW5.2, U3.18 (PA8)
/BUTTON_VOLT_-: R24.1, SW6.2, U3.19 (PA9)
/BUZZER: BZ1.1 (+), U3.27 (PB3)
/CC_INDICATOR: U3.8 (PA1); also elsewhere on the board
/CV_INDICATOR: U3.9 (PA2); also elsewhere on the board
/NRST: C8.1, J2.4, SW2.1, U3.6 (NRST)
/OCP_INDICATOR: U3.7 (PA0); also elsewhere on the board
/PB2: C21.2, R32.2, U3.17 (PB2)
/SCL: J5.1, R12.2, U1.10 (SCL/SNK_ISET), U3.32 (PB8), U4.3 (SCL); also elsewhere on the board
/SDA: J5.2, R13.2, U1.9 (SDA/SNK_VSET), U3.1 (PB9), U4.4 (SDA); also elsewhere on the board
/SWCLK: J2.3, U3.25 (PA14)
/SWDIO: J2.2, U3.24 (PA13)
/TEMP_ADC: R31.2, R39.2, TH1.1, U3.11 (PA4)
/TEMP_INDICATOR: R28.1, U3.29 (PB5)
/UART_RX: J4.1, U3.31 (PB7)
/UART_TX: J4.2, U3.30 (PB6)
/USB-C_EN: U1.12 (~EN), U3.13 (PA6)
/USB-C_Fault: U1.13 (FAULT/OUT2), U3.15 (PB0)
/USB-C_Fault_IN: U1.14 (FLGIN), U3.14 (PA7)
/USB-C_INT: R41.2, U1.11 (~INT), U3.16 (PB1)
/USB_FAULT_INDICATOR: R26.1, U3.12 (PA5)
/VOUT_FAULT_INDICATOR: R27.1, U3.28 (PB4)
AGND: C12.2, C18.2, C19.2, NT1.2, R11.2, R15.1, R16.1, U4.5 (DITH/SYNC), U4.17 (AGND)
CHASSIS_GND: H1.1 (1_1), R33.1
GNDREF: BZ1.2 (-), C1.2, C3.2, C4.2, C6.1, C7.1, C8.2, C11.2, C13.2, C14.1, C15.1, C16.1, C17.1, C20.1, C21.1, C22.2, D60.1 (K), D61.1 (K), D62.1 (K), J1.A1 (GND), J1.A12 (GND), J1.B1 (GND), J1.B12 (GND), J1.SH (SHIELD), J2.5, J3.2, J4.3, J5.3, NT1.1, R3.2, R6.2, R7.2, R18.2, R21.2, R22.2, R23.2, R24.2, R25.2, R33.2, R37.2, R38.2, R40.2, SW2.2, TH1.2, U1.17 (GND), U2.3 (GND), U2.4 (GND), U3.5 (VSS), U4.9 (PGND); also elsewhere on the board
unnamed: C19.1, R20.1
unnamed: D1.2 (A), Q1.G, R9.2, R10.1
unnamed: D60.2 (A), R26.2
unnamed: D61.2 (A), R27.2
unnamed: D62.2 (A), R28.2
unnamed: J1.A5 (CC1), U1.3 (CC1)
unnamed: J1.B5 (CC2), U1.4 (CC2)
unnamed: C11.1, C13.1, JP1.1 (A), U4.7 (VIN)
unnamed: R2.2, R3.1
unnamed: R7.1, U1.8 (ADDR/ORIENT)
unnamed: J1.A6 (D+), J1.B6 (D+), U1.1 (D+)
unnamed: J1.A7 (D-), J1.B7 (D-), U1.2 (D-)
unnamed: R8.1, U1.7 (EN_HVDCP/OUT1)
unnamed: R10.2, U1.15 (GATE)
unnamed: R40.1, U1.6 (~DEBUG)
unnamed: C2.1, U2.7 (BS)
unnamed: R1.1, U2.8 (EN)
unnamed: C5.2, R4.2, R5.2, R6.1, U2.1 (FB)
unnamed: R2.1, U2.2 (FS)
unnamed: C2.2, L1.1, U2.6 (LX)
unnamed: C9.2, U4.20 (BOOT1)
unnamed: C10.2, U4.19 (BOOT2)
unnamed: C18.1, R20.2, U4.15 (COMP)
unnamed: R14.2, U4.21 (EXTVCC)
unnamed: R15.2, R16.2, U4.6 (FSW)
unnamed: C14.2, C15.2, C16.2, C17.2, R17.1, U4.11 (VOUT), U4.12 (ISP)
unnamed: R18.1, U4.2 (MODE)
unnamed: C9.1, L2.1, U4.8 (SW1)
unnamed: C10.1, L2.2, U4.10 (SW2)
unnamed: C12.1, U4.18 (VCC)
VBUS: JP1.2 (B), Q1.D
VBUS_RAW: C1.1, D1.1 (K), J1.A4 (VBUS), J1.A9 (VBUS), J1.B4 (VBUS), J1.B9 (VBUS), Q1.S, R1.2, R9.1, U1.16 (VBUS), U2.5 (IN)
VOUT: J3.1, R17.2, R37.1, R38.1, U4.13 (ISN)

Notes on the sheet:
ST-LINK
Mounting Holes
STM32G030
VBUS -> 3v3 Buck
Display
NRST
Connectors
Audio
Temperature Monitoring
I/O
Programming
15mΩ chosen for ~3.3A max current limit.
effective resistance of 50k for 400kHz switching frequency
internal pull-up
Effective bleed resistance of 10k
maybe use fault in for safety mechanisms?
I2C address at 75H
I2C address at 42H

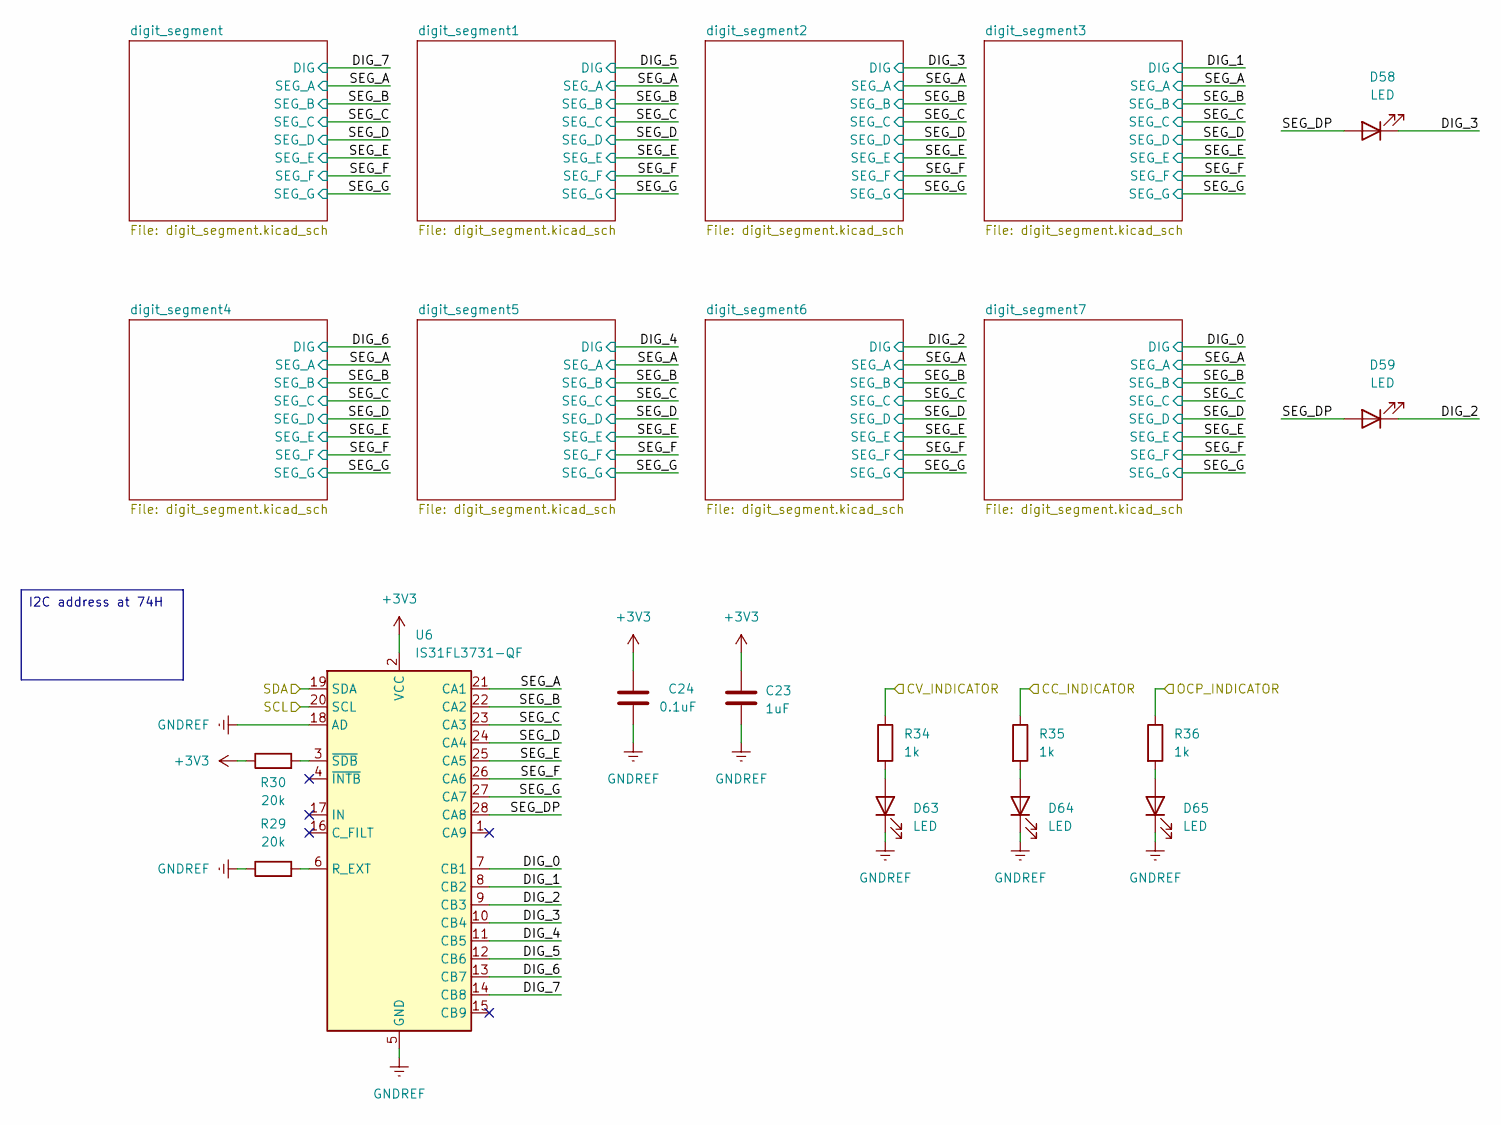
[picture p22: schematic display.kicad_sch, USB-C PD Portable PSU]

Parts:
C23: 1uF; C_0603_1608Metric; LCSC C15849
C24: 0.1uF; C_0603_1608Metric; LCSC C14663
D58, D59, D63, D64, D65: LED; LED_0603_1608Metric; LCSC C2286
R29, R30: 20k; R_0603_1608Metric; LCSC C4184
R34, R35, R36: 1k; R_0603_1608Metric; LCSC C21190
U6: IS31FL3731-QF; QFN-28-1EP_4x4mm_P0.4mm_EP2.3x2.3mm; LCSC C191206

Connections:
+3V3: C23.1, C24.2, R30.1, U6.2 (VCC); also elsewhere on the board
/CC_INDICATOR: R35.1; also elsewhere on the board
/CV_INDICATOR: R34.1; also elsewhere on the board
/OCP_INDICATOR: R36.1; also elsewhere on the board
/SCL: U6.20 (SCL); also elsewhere on the board
/SDA: U6.19 (SDA); also elsewhere on the board
/display/DIG_0: U6.7 (CB1); also elsewhere on the board
/display/DIG_1: U6.8 (CB2); also elsewhere on the board
/display/DIG_2: D59.1 (K), U6.9 (CB3); also elsewhere on the board
/display/DIG_3: D58.1 (K), U6.10 (CB4); also elsewhere on the board
/display/DIG_4: U6.11 (CB5); also elsewhere on the board
/display/DIG_5: U6.12 (CB6); also elsewhere on the board
/display/DIG_6: U6.13 (CB7); also elsewhere on the board
/display/DIG_7: U6.14 (CB8); also elsewhere on the board
/display/SEG_A: U6.21 (CA1); also elsewhere on the board
/display/SEG_B: U6.22 (CA2); also elsewhere on the board
/display/SEG_C: U6.23 (CA3); also elsewhere on the board
/display/SEG_D: U6.24 (CA4); also elsewhere on the board
/display/SEG_DP: D58.2 (A), D59.2 (A), U6.28 (CA8)
/display/SEG_E: U6.25 (CA5); also elsewhere on the board
/display/SEG_F: U6.26 (CA6); also elsewhere on the board
/display/SEG_G: U6.27 (CA7); also elsewhere on the board
GNDREF: C23.2, C24.1, D63.1 (K), D64.1 (K), D65.1 (K), R29.1, U6.5 (GND), U6.18 (AD), U6.29 (GND); also elsewhere on the board
unnamed: D63.2 (A), R34.2
unnamed: D64.2 (A), R35.2
unnamed: D65.2 (A), R36.2
unnamed: R29.2, U6.6 (R_EXT)
unnamed: R30.2, U6.3 (~SDB)

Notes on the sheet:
I2C address at 74H

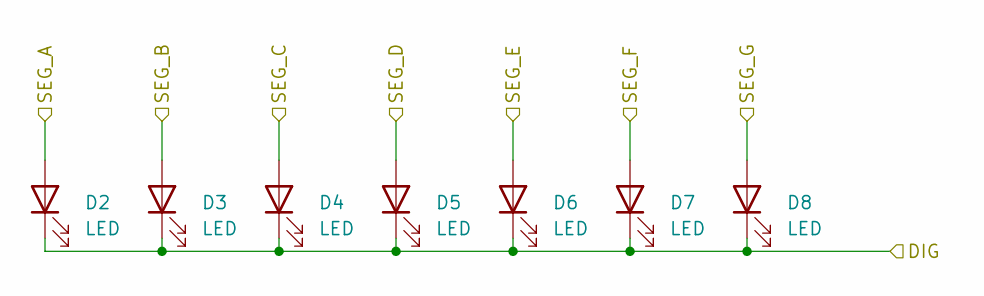
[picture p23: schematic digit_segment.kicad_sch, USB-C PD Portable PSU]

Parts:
D2, D3, D4, D5, D6, D7, D8: LED; LED_0603_1608Metric; LCSC C2286

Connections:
/display/DIG_7: D2.1 (K), D3.1 (K), D4.1 (K), D5.1 (K), D6.1 (K), D7.1 (K), D8.1 (K); also elsewhere on the board
/display/SEG_A: D2.2 (A); also elsewhere on the board
/display/SEG_B: D3.2 (A); also elsewhere on the board
/display/SEG_C: D4.2 (A); also elsewhere on the board
/display/SEG_D: D5.2 (A); also elsewhere on the board
/display/SEG_E: D6.2 (A); also elsewhere on the board
/display/SEG_F: D7.2 (A); also elsewhere on the board
/display/SEG_G: D8.2 (A); also elsewhere on the board

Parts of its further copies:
D9, D10, D11, D12, D13, D14, D15, D16, D17, D18, D19, D20, D21, D22, D23, D24, D25, D26, D27, D28, D29, D30, D31, D32, D33, D34, D35, D36, D37, D38, D39, D40, D41, D42, D43, D44, D45, D46, D47, D48, D49, D50, D51, D52, D53, D54, D55, D56, D57: LED; LED_0603_1608Metric; LCSC C2286

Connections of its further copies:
/display/DIG_0: D51.1 (K), D52.1 (K), D53.1 (K), D54.1 (K), D55.1 (K), D56.1 (K), D57.1 (K); also elsewhere on the board
/display/DIG_1: D23.1 (K), D24.1 (K), D25.1 (K), D26.1 (K), D27.1 (K), D28.1 (K), D29.1 (K); also elsewhere on the board
/display/DIG_2: D44.1 (K), D45.1 (K), D46.1 (K), D47.1 (K), D48.1 (K), D49.1 (K), D50.1 (K); also elsewhere on the board
/display/DIG_3: D16.1 (K), D17.1 (K), D18.1 (K), D19.1 (K), D20.1 (K), D21.1 (K), D22.1 (K); also elsewhere on the board
/display/DIG_4: D37.1 (K), D38.1 (K), D39.1 (K), D40.1 (K), D41.1 (K), D42.1 (K), D43.1 (K); also elsewhere on the board
/display/DIG_5: D9.1 (K), D10.1 (K), D11.1 (K), D12.1 (K), D13.1 (K), D14.1 (K), D15.1 (K); also elsewhere on the board
/display/DIG_6: D30.1 (K), D31.1 (K), D32.1 (K), D33.1 (K), D34.1 (K), D35.1 (K), D36.1 (K); also elsewhere on the board
/display/SEG_A: D9.2 (A), D16.2 (A), D23.2 (A), D30.2 (A), D37.2 (A), D44.2 (A), D51.2 (A); also elsewhere on the board
/display/SEG_B: D10.2 (A), D17.2 (A), D24.2 (A), D31.2 (A), D38.2 (A), D45.2 (A), D52.2 (A); also elsewhere on the board
/display/SEG_C: D11.2 (A), D18.2 (A), D25.2 (A), D32.2 (A), D39.2 (A), D46.2 (A), D53.2 (A); also elsewhere on the board
/display/SEG_D: D12.2 (A), D19.2 (A), D26.2 (A), D33.2 (A), D40.2 (A), D47.2 (A), D54.2 (A); also elsewhere on the board
/display/SEG_E: D13.2 (A), D20.2 (A), D27.2 (A), D34.2 (A), D41.2 (A), D48.2 (A), D55.2 (A); also elsewhere on the board
/display/SEG_F: D14.2 (A), D21.2 (A), D28.2 (A), D35.2 (A), D42.2 (A), D49.2 (A), D56.2 (A); also elsewhere on the board
/display/SEG_G: D15.2 (A), D22.2 (A), D29.2 (A), D36.2 (A), D43.2 (A), D50.2 (A), D57.2 (A); also elsewhere on the board

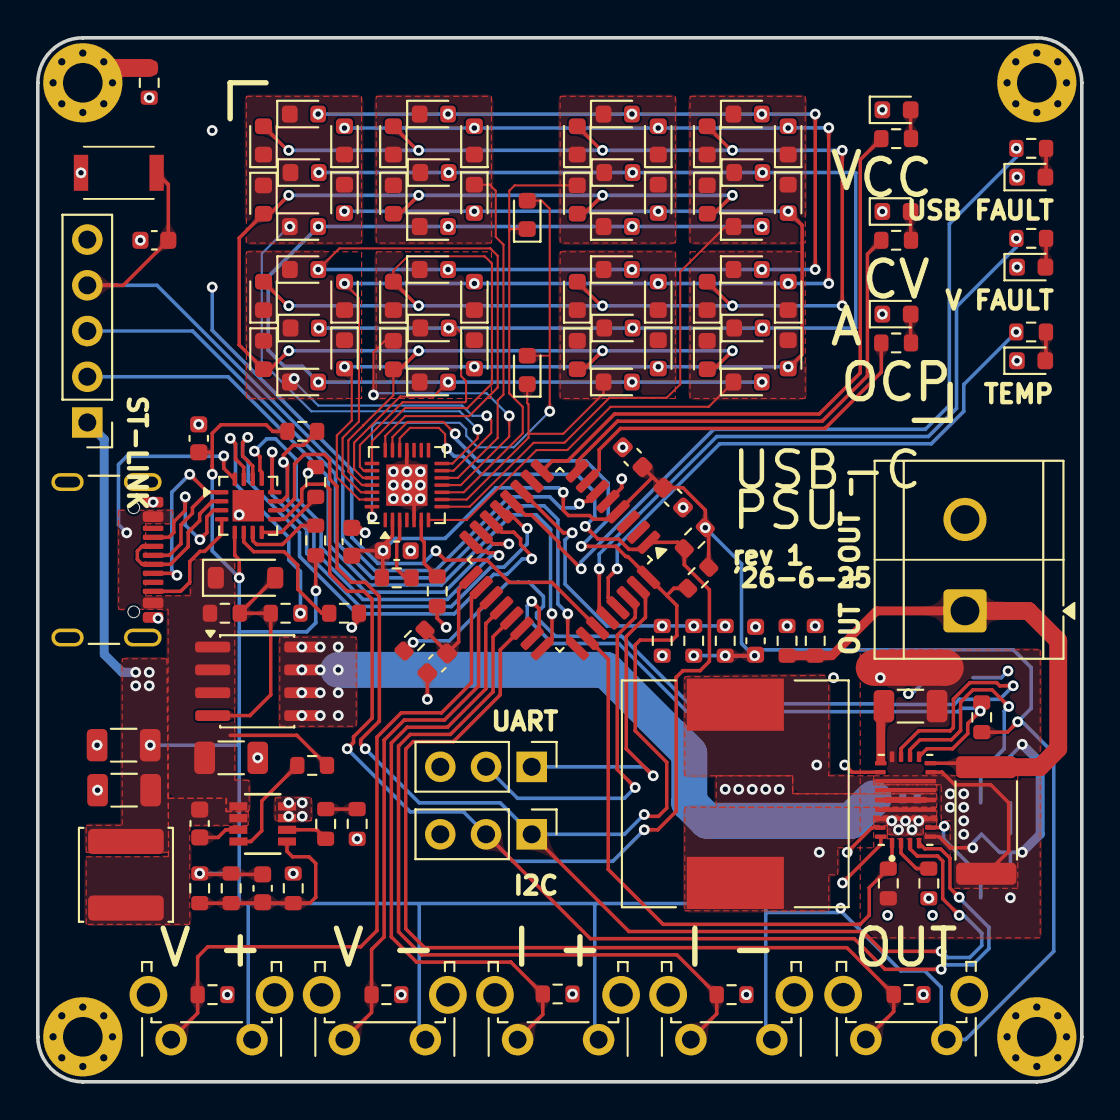
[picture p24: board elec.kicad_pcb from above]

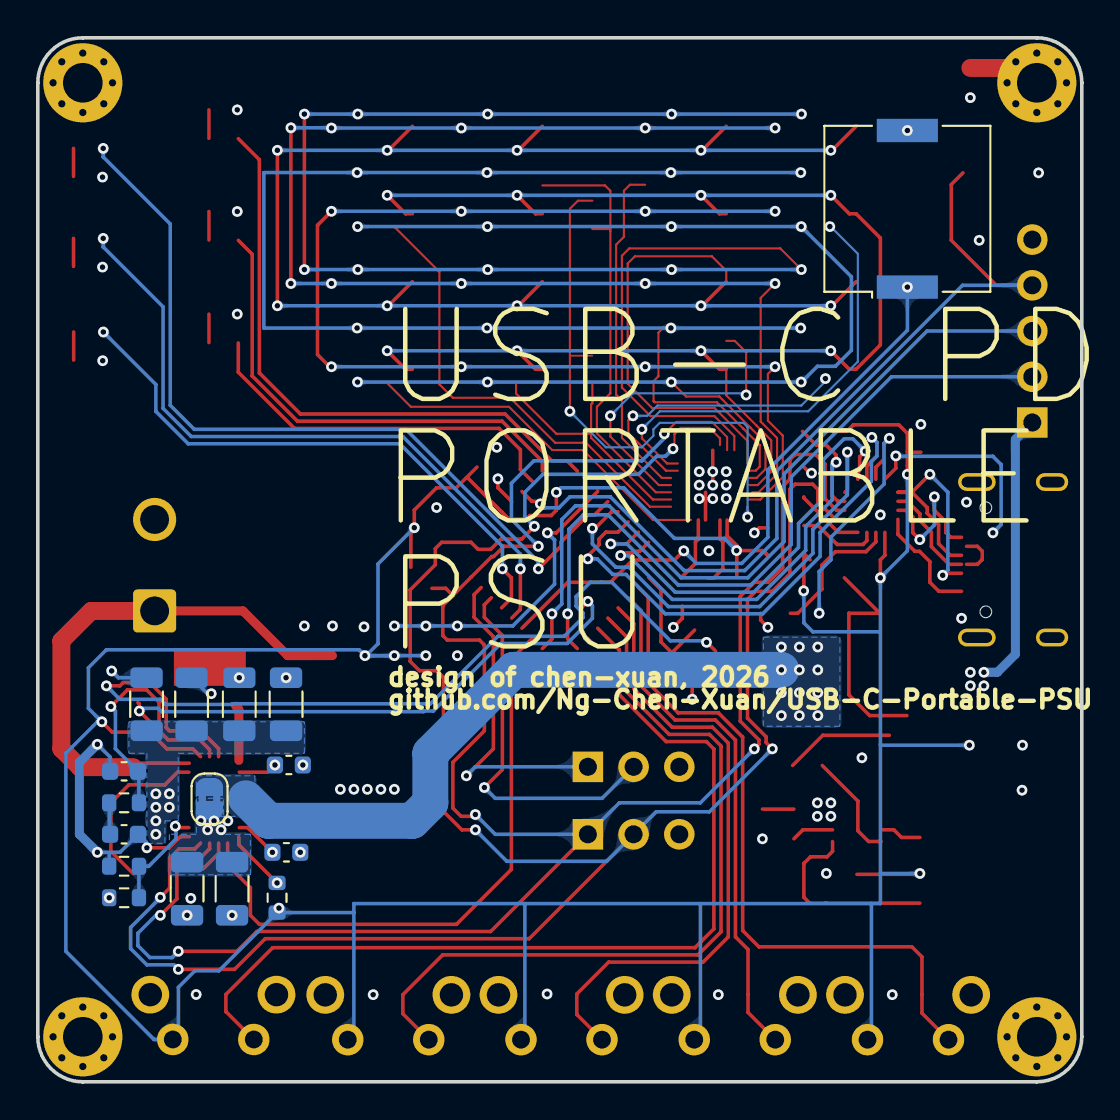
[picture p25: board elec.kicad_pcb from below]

Board: 4 copper layers, 58.0 x 58.0 mm, 157 parts (16 on the bottom side), 86 nets.

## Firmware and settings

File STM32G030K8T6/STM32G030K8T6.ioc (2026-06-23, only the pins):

Mcu.UserName=STM32G030K8Tx
PA0.Signal=GPIO_Output
PA1.Signal=GPIO_Output
PA10.Signal=GPIO_Input
PA13.Signal=SYS_SWDIO
PA14-BOOT0.Signal=SYS_SWCLK
PA15.Signal=GPIO_Output
PA2.Signal=GPIO_Output
PA4.Signal=ADC1_IN4
PA5.Signal=GPIO_Output
PA6.Signal=GPIO_Output
PA7.Signal=GPIO_Output
PA8.Signal=GPIO_Input
PA9.Signal=GPIO_Input
PB0.Signal=GPIO_Input
PB1.Signal=GPIO_Output
PB2.Signal=ADC1_IN10
PB3.Signal=S_TIM1_CH2
PB4.Signal=GPIO_Output
PB5.Signal=GPIO_Output
PB6.Signal=USART1_TX
PB7.Signal=USART1_RX
PB8.Signal=I2C1_SCL
PB9.Signal=I2C1_SDA
PC6.Signal=GPIO_Input

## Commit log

2026-06-13 Complete schematics
    [digit_segment.kicad_sch, display.kicad_sch, elec.kicad_pcb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]
2026-06-14 Populate LCSC Params, Assign Footprints, Update STM32CubeMX
    [digit_segment.kicad_sch, display.kicad_sch, elec.kicad_pcb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]
2026-06-15 Start PCB Layout Draft
    [elec.kicad_pcb, elec.kicad_sch]
2026-06-17 Layout of everything except display
    [elec.kicad_pcb, elec.kicad_sch]
2026-06-19 PCB layout
    [display.kicad_sch, elec.kicad_pcb, elec.kicad_sch]
2026-06-22 Completed Routing
    [display.kicad_sch, elec.kicad_pcb, elec.kicad_sch]
2026-06-22 Fix PCB layout mistake
    [elec.kicad_pcb]
2026-06-23 Added Bleed Resistor, Added Buzzer
    [elec.kicad_pcb, elec.kicad_sch]
2026-06-23 Generate Production files
    [BOM-elec.csv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]
2026-06-23 Update Public-facing Files
    [BOM-lcsc.csv]
2026-06-23 Fix PCB files
    [digit_segment.kicad_sch, display.kicad_sch, elec.kicad_sch]
2026-06-23 Update BOM
    [BOM-lcsc.csv]
2026-06-23 Initalise STM32CubeIDE Project
2026-06-25 Finalise PCB
    [BOM-elec.csv, BOM-lcsc.csv, digit_segment.kicad_sch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]
